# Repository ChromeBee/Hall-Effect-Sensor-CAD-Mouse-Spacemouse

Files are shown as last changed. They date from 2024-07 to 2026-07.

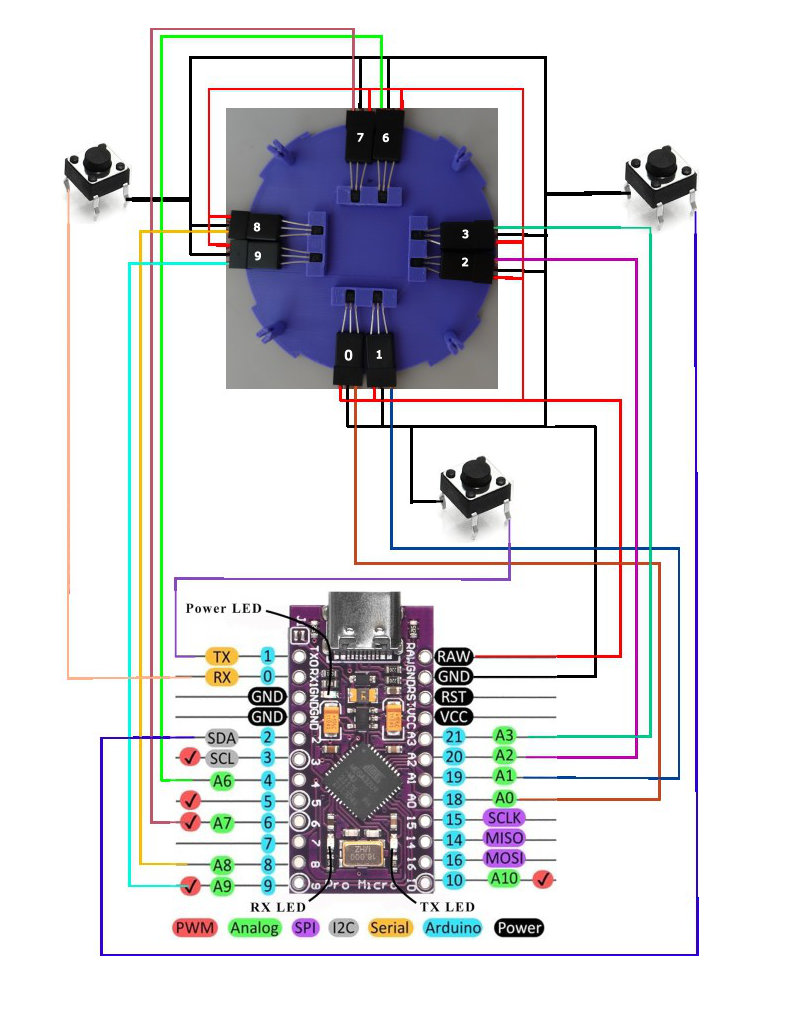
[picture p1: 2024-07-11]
HE Spacemouse Wiring Diagram.jpg

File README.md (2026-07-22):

Hall-Effect-Sensor-CAD-Mouse-Spacemouse
A 6 degrees of freedom mouse for CAD programs using cheap linear Hall Effect sensors for position measurement

2HE Spacemouse

This started as a thought project based on the Teaching Tech $20 CAD mouse code. This code works with the 3D ConneXions device driver so any program that works with the 3D connexions Spacemouse will work with his $20 CAD mouse and also this one. If it hadn't been for his project and the resulting code, I wouldn't have even considered this.

Luckily the thought project turned into a real one as I did my research.

The linear Hall Effect sensors used are the (SS) 49e variety. They are very cheap, I bought a pack of 40 for £10. 8 are required for this project. They are arranged in 4 groups of 2. 2 of the groups are parallel to the x-axis and 2 parallel to the y-axis.
These sensors have 3 pins. VCC, GND and output. With power connected, the output should give a value of half way between VCC and GND. i.e. if 5v is connected then with no magnet field detected the output should be 2.5v. If the north pole of a magnet approaches the sensor the output should decrease up to to a minimum voltage of 0.86v while if a south pole approaches then the voltage at the output should increase up to a maximum of 4.21v.
Using these sensors, the operation of the mouse can be described in a couple of pictures.

HSE default position

The red dots represent magnets suspended a short distance above each Hall Effect sensor pair. In their resting position (shown above) the sensors values are measured. Any change from these measured values represents a move of the joystick.

HSE forward position v2 HSE forward position

If the joystick is pushed forward slightly, the magnets move closer towards two of the Hall Effect sensors on opposite pairs (A & C in the picture), increasing the magnetic field that they detect and further away from the other two (B & D) which will detect less.
Because we can present only one pole of the magnet, we are restricted to only half of the possible output range. I chose to have the north pole being the one closest to the sensors as the analogue to digital converter was returning a value over half its possible range so I was getting the greatest range of values this way. Although I didn't know it at the time, the Arduino Pro Micro we are using to measure the outputs, also has the ability of switching to an internal ADC reference of 2.56 volts. Therefore if we present north poles to the sensors we should expect each sensor to output between 0.86 and 2.5 volts. So we don't lose much resolution.
So for the picture above, the sensors with the magnets moving towards them will output a decreasing voltage, while the two where the magnets are moving away from them will output an increasing voltage. If we take the values for the sensors at their resting positions and subtract the current values then The resulting value will go up as the magnet approaches and down when the magnet moves away. We will call this the sensor value from now on.

Now by adding the resulting values for sensors A & C and subtracting the values for B & D we get a result proportional to the amount of movement. If the value is positive in our example above we know it is a movement towards Sensors A & C and if it is negative then it is a movement away from them.

HSE twist position v2 HSE twist position

If we twist the joystick then diagonally opposite sensors will show a decreasing voltage as the magnet approaches while the other sensor in the pair will show an increasing voltage as the magnet moves away. 

By adding the values from sensors A & D and subtract the values from B & C we get a result that is proportional to the amount of twist. In our example a positive movement number will be a twist in the clockwise direction and negative will mean an anti-clockwise twist direction.

If we apply these values to the linear movement formula, we find that the the increased value for A is cancelled out by the increased value for D and B cancels out C. So we can tell the difference between a twist and a push. The same logic applies to the other movements.

magnet movement

When the joystick is tilted towards a pair of sensors then both their outputs show a decreasing voltage while the magnets on the opposite side will be moving away from the pair below it and so the sensors will output an increasing voltage.
Of course, the other pair parallel to the other axis will operate in the same way for tilts, twists and linear movements in the other axis.

When we push down on the joystick, the magnets get closer to all the sensors so the voltage output drops in them all and when we pull up on the joystick, the magnets move further away from all the sensors, so the outputs will increase.

DSC05601 v2

I tried various designs before I came up with the one that I'm going to take you through below. Including ones with multiple magnets per sensor pair but that is irrelevant if you just want to build what I came up with.

<h2>That is the operation now here is the implementation.</h2>

This build is also available on Printables. There may be more build details there but there will always be more technical details here on GitHub.
https://www.printables.com/model/940040-cad-mouse-spacemouse-using-hall-effect-sensors

<h3> Parts list</h3>
<ul>
  <li>Arduino Pro Micro</li>
  <li>8 of (SS) 49e linear hall effect sensors</li>
  <li>4 of 10x5x3mm Neodymium magnets
  <li>8 of servo sockets and leads</li>
  <li>3 of 6x6x5mm small tactile switches</li>
  <li>1mm diameter piano wire cut into 8 lengths of 8mm each and 4 lengths of 15mm</li>
  <li>8 of 0.2x12x4mm tension springs ( wire diameter 0.2mm, total length 12mm, length of spring portion 4mm and OD of 4mm </li>
  <li>1 of M4x40mm bolt fully threaded.</li>
  <li>3 of M4 Nut</li>
  <li>4 of M3x20 bolts to secure the bolt plate and hold the sensor plate the correct distance from the magnet plate.</li>
  <li>12 of M3 nuts for the above bolts.</li>
  <li>10 of M3x4mm heat press brass inserts</li>
  <li>2 of M3x8mm to hold on knob</li>
  <li>4 of M3x6mm bolts to hold on base</li>
  <li>4 of M3x6mm or M3x8mm bolts to hold on case</li>
  <li>Heat Shrink tubing or Insulation tape or liquid insulation to cover wire to wire solder joints</li>
</ul>



The mouse is made up of several layers or plates. The bottom plate holds the Arduino pro micro. This needs to be wired to the sensors and optional switches. The wiring diagram is in it's own folder in this project directory.
coloured render of HE Spacemouse with labels

I am using servo sockets to hold the Hall Effect sensors, however the default wiring colours for servo connectors doesn't match what is needed for the sensors. The middle pin on a servo is 5v and the connector will normally have a red wire to this, however it is ground on the sensor. With the angled side face up and the legs towards you, the left most pin is VCC, the middle pin ground and the right most pin the output. I swapped the VCC and GND wires on the servo sockets to avoid confusion.



To reduce the wires connected directly to the Arduino, I have joined the VCC pins of each pair together, also the GND pins and a GND wire for a switch. Then joined the 4 wires of VCC wires from the sensor pairs together to a single wire to go to the Arduino and the same with the GND wires. To make sure that the wires weren’t too long and to make things easier to wire. I attached the M4x40mm bolt to the bolt plate and the bolt plate to the sensor plate. I then mounted the sensors in their appropriate holders and held them all in place with an elastic band. This is what is shown in the picture above. The band was also useful for holding wires I didn't need at the time out of the way. 



These are then wired to the Arduino pro micro together with the sensor and switch output wires.
The Arduino is then mounted to the 3d printed Arduino plate and held in place with a short length of filament.



An M4x40mm bolt is then attached to the Bolt plate and this attached to the Arduino plate using M3x20mm bolts



4 of the 0.2x12x4mm tension springs are attached to the bolt plate. These fit in the slots on the centre column and are held in place with short (8mm) lengths of 1mm diameter piano wire.
A second set of nuts is added to the 20mm bolts holding on the bolt plate, then the sensor plate is placed on top and the sensors slotted into place.



Loading the software on to the Arduino pro micro and setting debug level to 1, we can ensure, by bringing a magnet close to each sensor, that the sensor works, is correctly connected and which pole of the magnet is being presented to it. Once we have identified the north pole of the magnet we can glue 4 10x5x3mm magnets into the magnet holder. The north pole is the one that causes the numbers to decrease when moved towards the sensors. The north pole should face downward, that is towards the side of the magnet plate with a slot in the area were the magnets go.

<b>Note:</b> Setting debug to 1 sets the reference voltage on the arduino pro micro to 5V. This debug value is only used for the initial build to ensure the Arduino is wired correctly and that the north pole of the magnet can be determined prior to mounting the magnets on the magnet plate. The 5V reference value means that the numbers will change no matter which pole of the magnet is presented to it. If the numbers go up then it is the south pole, if the numbers go down then it is the north pole. In other debug levels, the reference voltage is 2.5 volts and the output values won't change if the south pole of the nagnet moves closer. This would make the initial setup debugging more difficult. I have added this note After reading notes on change request #78 on AndunHH's Spacemouse code repository which is a code change for a version of this mouse. See : https://github.com/AndunHH/spacemouse/pull/78 Once the magnets are glued into place and the wiring verified this debug level is no longer needed.



Once the magnets are glued in we can add m3 x 4mm heat pressed brass inserts on the magnet holder and the case also the base if it is going to be used. I just used a soldering iron to push these into the corresponding holes.

location of brass inserts

The diagram above shows the location of the brass inserts.

Now we need to mount the magnet plate to the mouse. It goes over the M4 bolt and the springs attached to the bolt plate have to be mounted to the slots in the magnet plate using 4 x 15mm lengths of 1mm diameter piano wire.



4 more of the tension springs are attached to the magnet plate in the same slots. A second M4 nut is added to the M4 bolt and the wire holder is put on top. 4 more pieces of piano wire of 8mm in length and placed on the wire holder and the springs lifted and fitted on these.



An optional washer and M4 nut can be placed on top.

Set debug level to 2 in the code and upload it. Now test the movement of the magnet plate and verify that numbers go both up and down on all sensors.

The base is intended to be a weighted base and should be filled with something heavy and non metallic. I was thinking of cement, epoxy resin or modelling clay. 

Mount the base (if you are using it) using M3x6mm bolts and the knob using M3x8mm bolts.



Now make sure the knob is high enough so that when the case is put on the knob is clear of the case and there is sufficient movement in all directions. If not, adjust the top nuts on the M4 bolt.

Next put the buttons in the holes in the case and place the the case over the mechanism aligning the cut-out for the USB connector with the connector on the pro micro. Bolt the case in place using either M3x6mm or M3x8mm bolts.

The CAD Mouse/Spacemouse is now complete.

<h2>The Arduino now needs to be setup to emulate the Spacemouse.</h2>

This is the same process as the teaching Tech model and is covered on their Open Source Spacemouse model's Printables page at https://www.printables.com/model/864950-open-source-spacemouse-space-mushroom-remix

The process is also covered in the comments in the Arduino sketch. It involves setting up a custom Arduino board that the 3D connexion software recognises as a Spacemouse Pro Wireless.

The 3D connexions driver is fairly flexible on the range of values the mouse sends to it for it to work. To have the most flexible range, both in positive and negative directions, with debug set to 1, and analogRference(DEFAULT) I.e. 5 volts, the outputs should be reading around the value of 342. If the analogReference(INTERNAL) is set then, the mid range value should be around 684. You can adjust the distance of the sensor plate from the magnet plate to adjust this. Each corner can be adjusted independently.

<b>24-Nov-2024 Update</b>
I have found that with the magnets I'm using that a distance between the magnet plate and the sensors of just under 4mm works best. I have a small dowel stick that I've used as a pointer in some videos and its diameter is just under 4mm. If it just about fits, with a push, between the magnet plate and sensor plate then I'm about at the correct distance.

If the mouse works for tilting and twisting but not lateral movements of left/right and forward/backward, then the gap is too large and should be reduced. 

I have also added the TPU cap keeper that I added to Printables a few days ago. This, printed in TPU, fits on the knob cap and holds it to the knob, if loose. It wasn't needed for my first build but a subsequent print using a differet brand of filament, I found the cap was loose. This solves that problem.
<b>End-of-update</b>

This is what I've been able to discover that the button report can contain. The Spacemouse pro wireless supports 18 programmable buttons although the code indicates more. There are 4 bytes in the report and depending on what bit is set to 1 it causes the following to happen.
<TABLE BORDER="1">
<TR><B><TD>Bit Number</TD><TD>Byte 0</TD><TD>Byte 1</TD><TD>Byte 2</TD><TD>Byte 3</TD></B></TR>
<TR><B><TD>bit 0</TD></B><TD>Configuration Screen</TD><TD>Rotate 90 degrees</TD><TD>-----</TD><TD>Shift key</TD></TR>
<TR><B><TD>bit 1</TD></B><TD>Fit to screen</TD><TD>-----</TD><TD>-----</TD><TD>CTRL key</TD></TR>
<TR><B><TD>bit 2</TD></B><TD>Plan View</TD><TD>-----</TD><TD>-----</TD><TD>TAB key/Disable rotate</TD></TR>
<TR><B><TD>bit 3</TD></B><TD>-----</TD><TD>-----</TD><TD>-----</TD><TD>-----</TD></TR>
<TR><B><TD>bit 4</TD></B><TD>Right view</TD><TD>Hide design Browser</TD><TD>-----</TD><TD>-----</TD></TR>
<TR><B><TD>bit 5</TD></B><TD>Front view</TD><TD>Open File Explorer</TD><TD>-----</TD><TD>-----</TD></TR>
<TR><B><TD>bit 6</TD></B><TD>-----</TD><TD>Internet</TD><TD>ESC key</TD><TD>-----</TD></TR>
<TR><B><TD>bit 7</TD></B><TD>-----</TD><TD>Copy key</TD><TD>ALT key</TD><TD>-----</TD></TR>
</TABLE>

<b>09-Aug-2025 Update</b>
After a year of no code changes, I have made a couple.
The code has always had one pseudo button. By pressing the left and right buttons at the same time, it opens the 3DConnections configuration menu.
Now I have added two new pseudo buttons operated by pressing the front button and one of the other two buttons at the same time.

Pressing the front button together with the left button starts and stops rotation lock.
Pressing the front button together with the right button is fit to screen.

The three buttons pressed on their own change the view to plan, right and front.

All buttons can be reassigned to provide different actions through the 3DConnections configuration menu which you can get at by pressing both the button on the left and the button on the right simultaneously.

The actions described are for CAD software and may do different functions in different software. All have been tested with both Fusion and On-Shape.

The second change is to remove the Speed parameter in the code. This reduced the amount of movement permitted to 80% by default. As this function is also provided by through the 3DConnections configuration menu, it was redundant to have it in the code as well. This was a left over from the Teaching Tech Big Foot code which this code was originally based on.

You don't have to use my code with this mouse. I will point you to AndunHH's excellent GitHub spacemouse repository:
https://github.com/AndunHH/spacemouse

This code has frequent updates from multiple people, supports different mice hardware designs including this one and offers support for additional accessories such as LEDs and scroll wheels. The code is much more sophisticated than mine.

<b>14-Aug-2025 Update</b>
I have modified the code again. I never used the buttons on the mouse until recently. Having found the 'fit to screen' and to a much leser extent, 'rotation lock', useful. I decided to use the left and right buttons directly to implement these. That meant removing the 'Plan view' and 'Right view' from these buttons. I then decided that the front button should cycle through the three views. So now pressing the front button will give a different view on each press, cycling from 'Front view' to 'Right view' to 'Plan view'. The front button together with the left button now rotates the view by 90 degrees and the front button together with the right button removes the project browser in Fusion and brings up a number pad in On-Shape. This is effectively implementing the function of 8 buttons using only 3.

Pressing the left and right buttons together brings up the 3Dconnections configuration menu as normal.

If you are intending to re-map the buttons, then having a button that changes what button it is pretending to be each time it is pressed makes that more difficult, however by setting the variable cycleButton from true to false will stop this and change the mapping back to the previous version.

<b>20-May-2026 Update</b>
This is going to seem like a blog post.

There are three changes been added to the code, all around movement. I'm going to talk about them in reverse order.

The last change added (C012) uses all the sensors in all movement calculations. Previously only the z axis movements did this. I had tried this change previously but had to roll it back when it made the mouse behave worse but I subsequently realise that was because I made a mistake in the formulas I used, so now they are back and working. If you prefer the previous movement calculations you can have those by commenting out the line #define include_C012

The next change (C011) is, I have added weights to all the movement calculations. I thought zoom was too sensitive and wanted to reduce it while increasing the sensitivity to X and Y axis lateral movement. So now each movement direction has a weight associated with it that is used to calculate how much the movement contributes to the total movement seen on screen. After playing around with various values on both my mice for several days (one with the crossed 85A TPU springs (see https://www.printables.com/model/1087923-hall-effect-spacemouse-cad-mouse-with-tpu-springs) and one with Innerbushmans alternative magnet plate 95A TPU (See https://www.printables.com/model/1566497-alternative-tpu-suspension-for-spacemouse)), I have ended up with values that are almost back to what the original code had built-in when I was only averaging sensor pair values (i.e. if I used 4 sensor pairs in the calculation I divided by 4. if I used only 2 sensor pairs, I divided by 2). This change works by multiplying each movement with its associated weight and dividing it by a global weight divisor. You can make the mouse more sensitive and react faster in the required directions by increasing the weights or globaly by decreasing the weightDivisor value.  I had the transXWeight and transYWeight set to 12 and the transZWeight set to 2 for a while before deciding that, for me the mouse was too sensitive on X and Y axis movement and the zoom was too slow. I encourage you to play with values and see what works best for you.

This change also opens up the possibility of using, for example, one of the double button pushes that I never use to switch the mouse between different sensitivities by using the button push to change the weightDivisor value between a set of pre-set values. That would be pretty simple but then you'd want some way on knowing what the mouse was currently using. The obvious answer would be one or more addressable LEDs whose colour would indicate the pre-set in use. 

The final change (C010) and the first added to the code is actually by Jonas Edvinsson on Printables. He added and posted a snippet of code that ignores small accidental movements that are below a particular threshold of the main movement. By default if a movement is less than 35% of another movement then it is ignored. I added this shortly after Jonas posted it but had other changes I wanted to try to see if they impacted his code. This may affect mouse calibration so I have included a method of excluding it by commenting out the line #define include_C010.
I hope you like these changes.

In other news, one of my mice died. I thought it was Pro Micro but it turned out it was a short across the 5V to ground on the sensor plate. Naturally it was the mouse where the sensors are stuck in using liquid insulation and it was no longer liquid nor soft. I couldn't remove any of the sensors so I decided to construct a new sensor plate and wanted to try an new method of getting power to all the sensors.

Two wiring options

I finally decided to use copper tape and it works perfectly, even if the changes I made to the sensor plate for it are less than ideal. I still used liquid insulation on the sensors to protect the sensor wires. I hope I don't regret it.

new sensor plate wired

Later I found a 1.25mm picoblade connector on my desk and discovered the 49e hall effect sensor leads fit beautifully and it is so much smaller than the servo connectors. If I need to construct a new sensor plate again, I'll be using these to connect up the sensors.

Picoblade
<br>
<b>22-Jul-2026 Update</b>
I've been thinking about the deadzone for the last couple of weeks. I have quite a high value of 40 for this, while from the comments on Printables and other places, some people are using a much lower value, even as low as 4. 
There are 3 main reasons for having a deadzone.
<ul>
<br>
<li>The first reason is to ignore jitter or variations in the readings the Arduino's analog to digital converter gives when reading the sensors output voltages when in its resting (in the centre position). When viewing debug outputs, the numbers appear to jump about a lot but when I measured the maximum variation over 1000 readings I found it was only 2 across all sensors. This means that a deadzone value just above this would be sufficient for this reason. </li>
  <br>
<li>The second reason is to deal with any possible failures in the centring mechanism in returning the mouse to the exact same resting position after any movement. No matter if the centring mechanism uses metal or TPU springs, rubber, elastic, silicone or some other means, the centring may not be perfect and we want to ignore any minor variations in returning to this position.</li>
  <br>
<li>The third reason is personal preference. Is the mouse too twitchy or not sensitive enough to your touch?</li>
  <br>
</ul>
I'll stick to a value of 40. This works best for me.

<b>More code changes</b><br>
I've also made a couple of updates to the code.

<br>The first is related to the above. I've added a routine that will auto recentre the mouse if the readings for the current centre resting position is more than a certain threshold value away from what was previously recorded (C013). It determines this by ensuring all measurements, for a period of time, remain within this threshold of what it believes is the new centre position. I tried other methods for auto re-centring but this one seems to work best.
<br>
The other change is related to switching between different sensitivities. Something I mentioned considering in my last update. By pressing the centre and right buttons at the same time, it will switch between normal, half and quarter sensitivities (C014). This change was enabled by a previous change (C011) which allowed different movements to have different weighted priorities. 
Both these changes can be switched off by commenting out the associated #define line that says to include them.
<br>
I also did a bit of a tidy-up to the code.

Shield: [][cc-by-nc-sa]

This work is licensed under a
[Creative Commons Attribution-NonCommercial-ShareAlike 4.0 International License][cc-by-nc-sa].

[][cc-by-nc-sa]

[cc-by-nc-sa]: http://creativecommons.org/licenses/by-nc-sa/4.0/
[cc-by-nc-sa-image]: https://licensebuttons.net/l/by-nc-sa/4.0/88x31.png
[cc-by-nc-sa-shield]: https://img.shields.io/badge/License-CC%20BY--NC--SA%204.0-lightgrey.svg

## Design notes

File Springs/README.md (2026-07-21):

<h2>Springs</h2>
I have had a large bag of 0.2 mm tension or extension springs for years. The smallest length of spring in the bag, 12mm, is what I've used for this project.
The exact same spring as I've used seems to be difficult to find at a reasonable price. Even though I don't need them, I thought I would try a couple of different sizes to see how they perform.
I bought some 0.4x12x4mm and some 0.3x10x3mm springs from Amazon UK.

DSC05641 small

I mounted the springs on the bolt plate/magnet plate/wire holder as they would be in the completed CAD mouse but left off the sensor plate. 
In the photo the purple/pink one on the left has the 0.4x12x4mm springs, the grey one in the middle has the 0.3x10x3mm springs and the final blue one on the right is my prototype with the 0.2x12x4mm springs.
All work but the effort needed to move them varies. The 0.4x12x4mm springs, in my opinion, requires too much force to move.
The 0.3x10x3mm springs seem to require just slightly less force to the 0.4x12x4mm spring. The shorter length meaning that the spring is stretched more and offers more resistance
The 0.2x12x4mm springs are very light to move in comparison to the other two.

The springs are stretched to about 20mm in the home position so a longer spring should work and being under less tension, it should be easier to move.
However it needs to be short enough to pull the magnet plate back to the home position when the mouse knob is released. Remember that the tension can be adjusted somewhat by moving the wire holder further up or down the M4 bolt.

Another way to reduce the tension is to install a second wire holder on the bolt for the lower springs. The picture below shows an example of this. Although in the example it is just above their original position. The wire plate could be moved further up the M4 bolt.

DSC05642 crop small

Another example with the plate moved further up the M4 bolt.
DSC05650 small

I thought of another way of reducing the tension when using 0.3x10x3mm springs. Fewer springs.
DSC05654 small

I removed alternate springs from the upper and lower sections. This seems to work very well. It still centres and moves in all directions but easier.

A search of eBay.co.uk for 0.2mm tension springs does provide listings of some suppliers of 0.2x10x3mm and 0.2x15x3mm springs. I haven't tried them but both sizes should work (in theory).

-------------
YouTube recommended a video on the IndyMower to me. https://youtu.be/UnKOp4rhu7I?si=PoE8raFwQZSphymA
In this video Nicodem Bartnik used TPU springs as part of a bumper sensor. YouTube has been recommending a lot of TPU videos to me recently so I took the hint and tried to 3D print TPU springs for the mouse. When I was going through the original thought experiments prior to starting anything, I had considered using those small rubber bands that were popular about 10 years ago for making friendship bracelets and other such items.

The TPU spring I've come up with is printed flat and has a custom Wire holder (now TPU holder).

DSC05643 small
DSC05644 small
DSC05646 small

This "spring" has a square cross section of 2mm across. Although it works, the tension is too much to allow the mouse to move freely. So I reduced the size to 1mm cross section.
DSC05648 small

This works much better. Certain movements are of equivalent tension to the 0.3mm springs while other movements are easier. It certainly feels usable.

I'm going to stick with my 0.2mm springs but I've put the STL files for the 1mm crossection TPU spring and the matching holder in a subdirectory here should anybody wish to try it.

<b>18-Aug-2024 Update:</b> For some reason, I can't leave this alone. I modified the design of the TPU spring and created STL files for a 0.8mm and a 0.6mm version. I have put these in the spring STL directory. I was going to leave it at that but then I decided to print them. I've tried both in one of the test prints. The 0.6mm one feels quite like the 0.2mm springs I'm using and the 0.8mm one just adds a bit more tension. I don't know if these will last long term but they are cheap to make and worth a try if you have difficulty getting the springs.

<b>16-Nov-2024 Update:</b> I think I've cracked it and now have the perfect TPU "spring" version. It might even be better than the normal spring version.
Mechanisim and case

This uses two TPU "springs" that are slightly longer and with thinner mounting hooks so that two of these "springs" can be used at the same time. One of the issues with the TPU springs was that a pendulum like rotatary oscillation could occur. It was simple to eliminate by twisting the two TPU hooks located above and below the magnet plate in opposite directions. This twist in the springs would stop the oscillation but also put a rotational strain on the M4 nuts which could cause them to loosen over time. This design counteracts that but applies the same principle.

<b>Additional parts needed:</b>
<li>2 prints of either of the "Thin TPU spring 0.6x16mm.stl" or "Thin TPU spring 0.6x17mm.stl" obviously printed in TPU. (I used 85A TPU)</li>
<li>1 print of TPU Bolt Plate printed in PLA. This is just a shorter version of the orininal bolt plate without spring mounting slots. The original can still be used.</li>
<li>2 prints of the TPU hook.</li>
<li>1 print of the magnet plate 0.3 from the original model. This is the magnet plate for 0.3mm springs.</li>
<br>
I am currently using the "Thin TPU spring 0.6x17mm.stl" with the TPU bolt plate. I have used both "springs" with both bolt plates and all combinations work. It is just down to how tight you want the mouse to feel. 

The two "springs" are mounted so that one twists the mechanisim on one direction while the second twists it in the other cancelling out the rotational strain.
I hope seeing this in pictures helps to explain what I mean.

Parts for TPU assembly

One spring is mounted as normal to the TPU hook plate.

Added to lower bolt plate

The second one is also added to the same hook plate. I have mounted the first one with the end hooks on the bottom TPU Hook mount and the second with the centre on the mount. That is just how I did it and it doesnt really matter how it is done. I then mounted this to the bolt plate using an M4 40mm bolt and an M4 nut. <b>Note the spring is mounted so the ends are in the middle of the area that sits below the sensors.</b>

Magnet plate added

To add clarity, I have added the second TPU hook plate and magnet plate at this point but it should be mounted to the arduino plate and passed through the sensor plate before these are added. The magnet plate is connected as normal to one of the TPU springs.
Second set conneted to magnet plate

The second spring is now connected to the magnet plate but its mounts are connected to an ajacent slot to the previous spring. In my case I rotated the magnet plate slightly counter clockwise and located the spring in the next slot.

completed mechanisim

I then did the same again with the end of this spring when mounting it to the top TPU hook, rotating it counter clockwise so the end fits in the next slot along from the one that is vertically above the slot on the magnet plate I have just fitted the middle part of the spring.

completed mechanisim

The printed washer and final M4 nut go on top. The nuts should be tighted in such a way that each magnet is centered over a sensor pair.

Assembled device front and high

To complete the mouse, I have taken the idea from the build by Rares Paul on Printables and soldered the Vcc leads of each of the sensor pairs together and conected the Vcc of each pair together with a wire then repeated the same for the ground leads (rather than use the servo connectors used previously). While Rares Paul used hot melt glue to insulate the soldered leads, I used liquid insulation because I had some. The result, I think, looks quite neat. I have also added silicone none slip feet to the arduino plate as trialed in my video, https://youtu.be/bVAX9b2wB6A?si=tlR51EHB5Pdp-rGi - The final step is to put on the case and the knob.

Both mice together V1

When I printed the first mouse, I had intended to put it in a navy blue case which is why the internals were printed in the same colour. It first was in a grey case with a navy knob, before I put it in the dark grey and gold combo. This one I printed in the dark grey, intending to prnt the case in dark grey and a different bright colour but ended up with the Navy and Purple I used for my Cyberpuck design. 

I have decided they should swap cases. I now have the grey and gold mouse beside me with the TPU "spring" mechanism and I really really like it.

<b>24-Nov-2024 Update</b>
I was a bit concerned that the TPU spring holder being used could interfere with the mounts on the knob. I haven't experienced any problem, but once I had the thought, I coundn't let it go so I created a version with a smaller diameter TPU Spring Holder. This of course needed different TPU springs, so I created them as well. These can be found in the smaller TPU Hook subfolder of the STL folder. I picture of the resulting mouse is below.

small TPU hook mounted

<b>09-Aug-2025 Update</b>
Yesterday I came across an interesting YouTube short - A demonstration of a different design of TPU spring from someone called Trev-erse.

New TPU spring design by trev-erse small

If I were starting now, I might use this. I can see it attached to the base, PCB or sensor plate and directly to the magnet plate. it could make for a smaller design.

<b>14-Aug-2025 Update</b>
OK, I had to try it. I created a wave spring and a method to mount it to the mouse.
Full details in the 'experimental wave spring' directory.
https://github.com/ChromeBee/Hall-Effect-Sensor-CAD-Mouse-Spacemouse/tree/main/Springs/Wave_Spring_Experiment

<b>18-Feb-2026 Update</b>
InnerBushman on Printables has created a very interesting magnet plate TPU spring alternative that I want to bring to peoples attention.

CAD mouse small

You can find it at https://www.printables.com/model/1566497-alternative-tpu-suspension-for-spacemouse

I now have the 0.5mm version printed in eSun 95A TPU installed in my blue mouse and can confirm it work very very well.

<b>08-Mar-2026 Update</b>
InnerBushman, when he posted the alternative TPU spring for the Spacemouse, also included a case which was much smaller than the smaller case version I already posted here. That original smaller case version was for the TPU spring version I posted on Printables. InnerBushmans alternative spring doesn't require mounting points above and below the magnet plate so the mouse can be made much smaller.

When I designed the original case, I used variables (parameters in Fusion) to represent the various sizes, so using InnerBushmans case height as a guide, I changed some of the variables to have a case of the same height as his based on the original design. I have now posted that on Printables. Changes need to be made to bolt sizes to get the mechanisim to fit but the changes are simple.
See: https://www.printables.com/model/1626668-alternate-case-for-alternative-tpu-spring-for-spac

His design opens up other possibilities. I played around with using his spring higher up the knob where the fingers hold it. This should give the best control but while it worked well for most movements, it didn't work with tilt because of the changed pivot point. There was always a degree of lateral movement introduce with the tilt.

knob original magnet plate with Alt TPU spring

This however got me wondering... Can we put the magnet plate there and have the sensors mounted so they appear inside the knob itself? Then the only thing outside the knob would be the buttons and the pro micro ( and the mount for the sensors and the rest of the hardware).

I am aware that there are other mouse versions using similar springs such as this from LeoSpaceLab. https://youtu.be/LWE_vR1oFRo?si=dDvz3KJTkTcSgacW ( not a 6DOF mouse though the spring is) and Razberry on YouTube has a series where he tries to build the perfect mouse. This version by InnerBushman is for my mouse and and I know it works.

<b>21-Jul-2026 Update</b>
I woke up one morning wanting to create a dual material version of InnerBushmans combined TPU spring and Magnet plate. I let it lie for a couple of days but couldn't get it out of my head, so here it is.

3 PLA and TPU 3D printed springs

With this version the TPU spring is embeded within the PLA Magnet plate. You don't need a fancy printer to make this. The TPU spring is printed first, then the PLA outer part is printed but the print is paused two layers before the end (0.2mm layer height) and the TPU spring inserted before continuing the print.

In the picture above, The top version has the spring inserted the wrong way around. The middle one used 83A TPE and it was too floppy. The bottom one is the one I'm using at the moment and the spring part is printed in 95A TPU.

mouse with double material spring

Is it any better than the InnerBushman version? Good question. I think the answer to that is probably no. It feels slightly different but that could just be my imagination. Anyway the STL files for this are available the STL directory together with the FreeCAD design file.

Yes, this is the third CAD program I've used for updates to the mouse. I'm trying FreeCAD after a couple of issues with both Fusion and OnShape.

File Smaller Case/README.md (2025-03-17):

<h2>Smaller Case</h2>
<b>This is for the TPU spring version (see springs section or remix on Printibles.com)</b>

Smaller Case with Normal size

<p>This was not an exercise in reducing the size of the CAD mouse, but in making it easier to use.</p>
<p>I thought that moving the magnet plate closer to where the fingers hold the knob would perhaps make it easier to control without getting other unwanted movements</p>
<p>The theory is this. If you hold a broom handle horizontally in the middle, it is easy to move it vertically without it twisting. Now if you move your 
hand away from the middle of the broom handle, it will try to twist because the forces acting on it are unbalanced. The same is true with the CAD mouse. Without the case and knob, It is easier
to move and control the movement of the magnet plate by holding it directly. Adding the knob moves the placement of the fingers higher up
and the springs fight any lateral movement the fingers try to apply, applying a rotation force with the fingers as the pivot. Moving the magnet plate closer to where the fingers are placed 
should reduce this.</p>
<p>The idea was to move the magnet plate so its bottom was flush with the bottom of the knob. This doesn't affect the operation of the mechanism but maybe could make it
  easier to move the knob laterally.</p>
<p>The first step was enlarging the hole at the bottom of the knob so the magnet plate can fit and moving the mounts for the magnet plate further up the knob to a
position that aligns the bottom of the magnet plate to the bottom of the knob. This lowers the knob so the top of the case needs to be lowered 
by the same amount. Doing this breaks some of the rest of the model so other case changes need to be made to counteract this such as the
curve or the case needing made tighter and reducing the internal lip so that it doesn't interfere with the bolts.
</p>
<p>The internal mechanism remains unchanged. The only changes are to the knob and the case and the buttons (1mm longer).
I have also hollowed out the knob cap more so there is less chance it interfering with the M4 bolt, though I'm still using the original cap version.</p>
<h2> Is it worth it?</h2>
<p>Good question. I can't detect any major improvement with the movement so if you are happy with the original version, I wouldn't change it.
If you fancy a smaller version, this is only 6.25mm smaller but why not try it. It only costs the price of the filament and 4 brass heat press inserts.</p>
<h2>Update 17-March-2025 Base for smaller case</h2>
<p>I've added an STL file for a base to fit the smaller case version. Birdy67 on printables pointed out that the original design base didn't fit well with the smaller case. As I don't use the base myself, but use homemade silicone feet on the Arduino plate, I hadn't realised that the changes to the case would also affect the base.</p>
<p>Creating the base was easy as it was already part of the design and the modifications I made for the case were automatically reflected in the base so I just needed to export it. I have not printed it myself as I don't need it, so it is untested.</p>
<p>I apologise to everyone that has encountered this issue. I hope this new part fulfils you needs.</p>

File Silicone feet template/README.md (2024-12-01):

This directory contains the STL file for the template I used to create silicone non slip feet on the bottom of the Arduino plate on the CAD mouse as shown on the YouTube video https://youtu.be/bVAX9b2wB6A?si=D21PwzSWIdShig4m

I don't want to use the weighted base if I don't have to, so this is a way of holding the mouse in place without it. It would also be possible to use the same principles to add silicone feet to the Base as well but I haven't tried it.

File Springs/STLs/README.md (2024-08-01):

STL files for TPU replacement for the springs. The TPU Spring should be printed in TPU while the TPU holder needs to be printed in PLA or equivalent.
The standard Magnet plate can be used with this.
See README.md in Springs directory for more information.

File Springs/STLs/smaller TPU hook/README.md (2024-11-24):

This is the set of modified model parts for the small hook version of the TPU springs.

It is just the TPU springs with the smaller fixings and the associated hooks to hold them.
The smaller hook increases the distance between the magnet plate and the hook so the spring has to be slightly longer.

I am using the TPU Spring 0.6x18mm version. If you want a tighter feel, use the 17mm version.

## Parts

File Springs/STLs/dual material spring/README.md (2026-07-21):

The STL and FreeCAD design file for the dual material spring can be found here.

This is a remix of the Innerbushman alternate spring/magnet plate design. Print the spring in TPU first
then the magnet plate/ spring holder second pausing the print befor it closes the top. This is two layers before
the print finishes if printed with a 0.2mm layer height. You can then insert the TPU spring, checking that the 
orientation is correct and then continue the print.

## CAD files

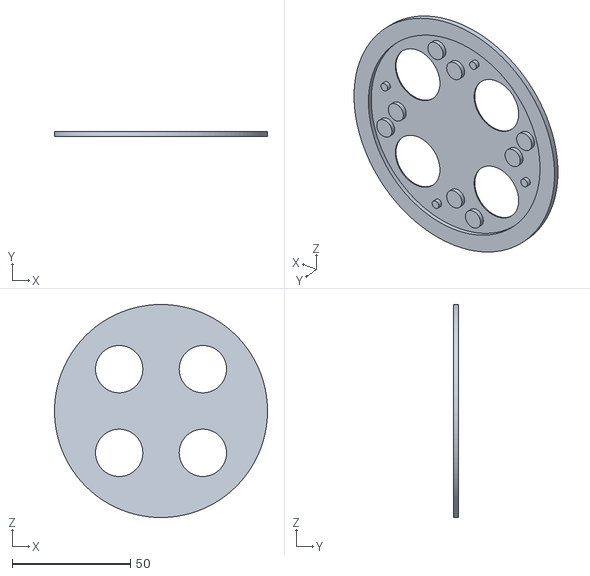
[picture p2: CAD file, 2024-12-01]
Silicone feet template/silicone template.stl
90.0 x 2.00 x 90.0

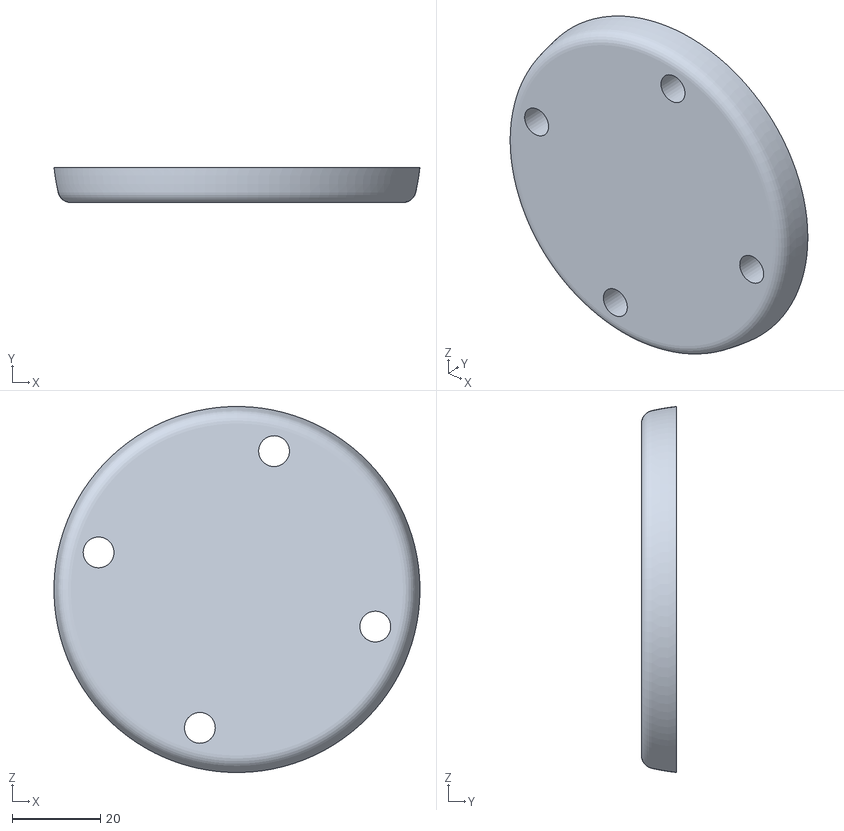
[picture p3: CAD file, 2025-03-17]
Smaller Case/Base for smaller case.stl
83.0 x 8.00 x 83.1

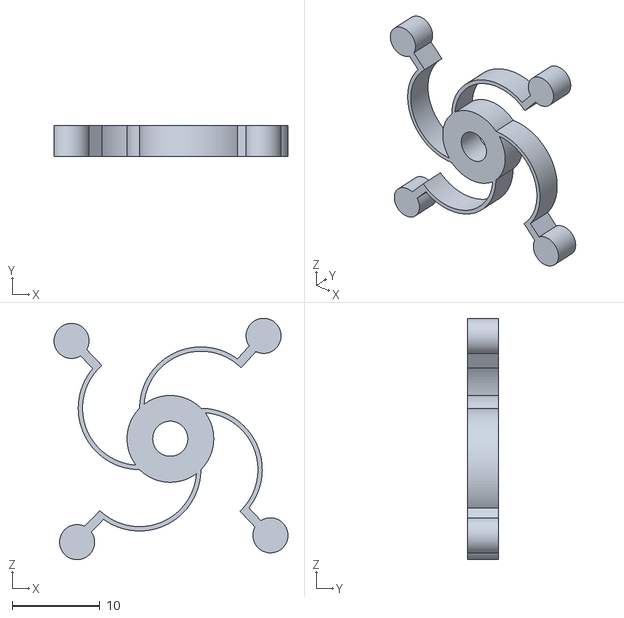
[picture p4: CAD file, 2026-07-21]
Springs/STLs/dual material spring/Alternate TPU spring for spring holder.stl
26.7 x 3.50 x 27.5

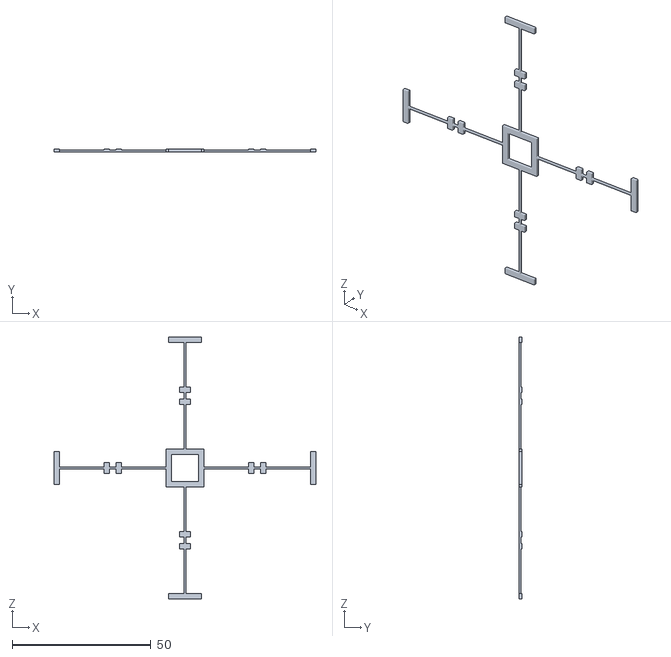
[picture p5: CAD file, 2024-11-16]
Springs/STLs/Thin TPU Spring 0.6x16mm.stl
94.4 x 1.00 x 94.4

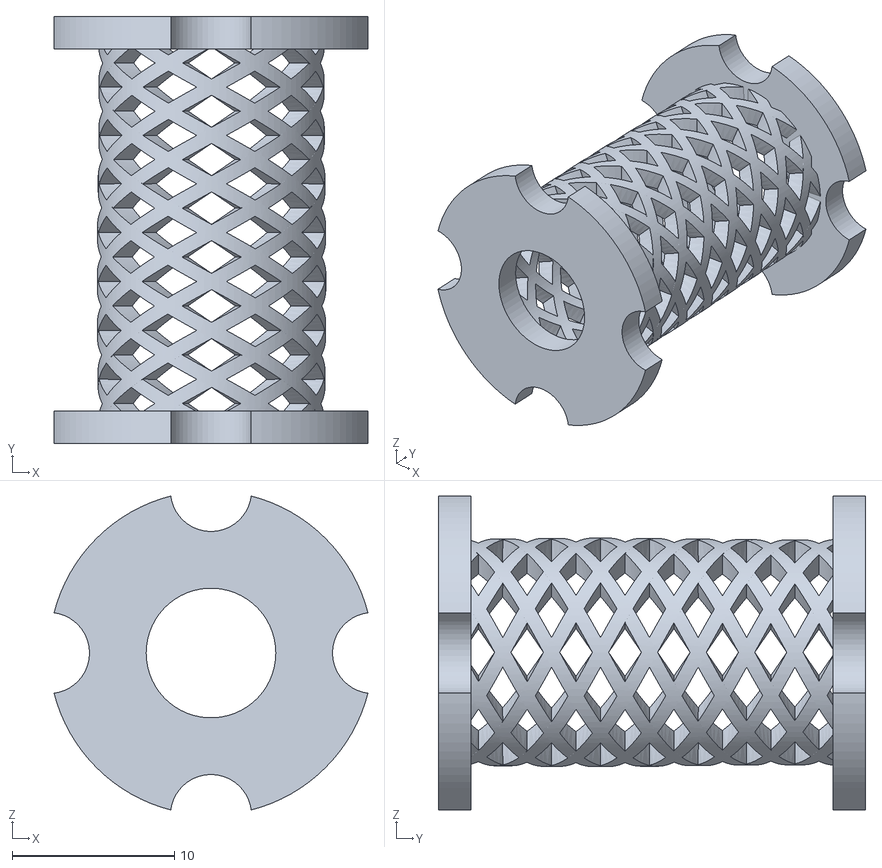
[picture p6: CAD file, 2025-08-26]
Springs/Wave_Spring_Experiment/Wave Spring for 95A TPU v3.stl
19.4 x 26.4 x 19.4

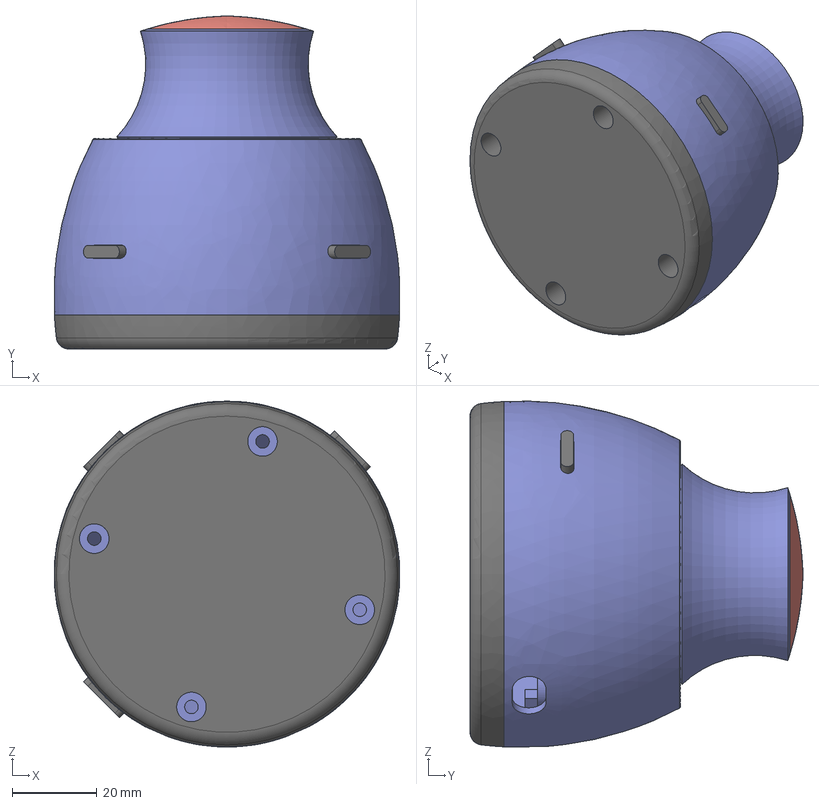
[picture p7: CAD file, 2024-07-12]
STEP file/Hall Effect Spacemouse.step
81.7 x 78.8 x 81.8 mm

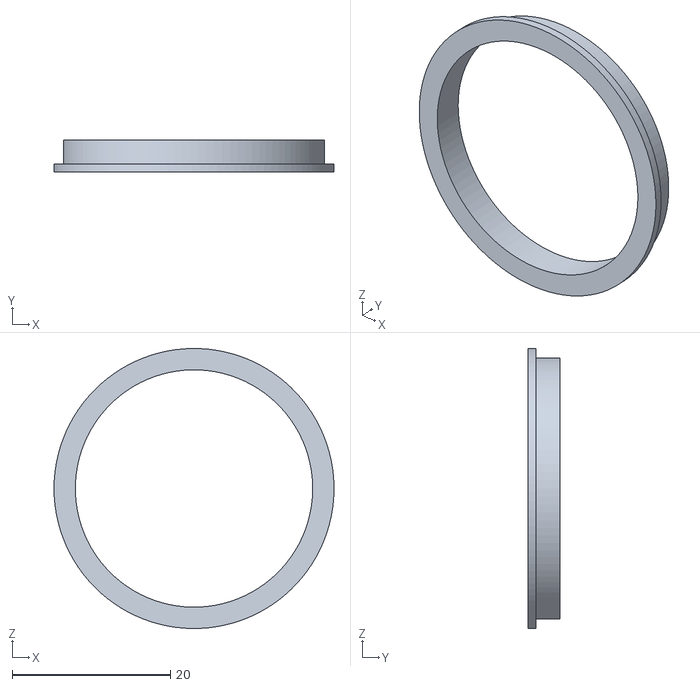
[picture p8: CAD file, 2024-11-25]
STL Files/TPU cap keeper.stl
35.4 x 4.00 x 35.4

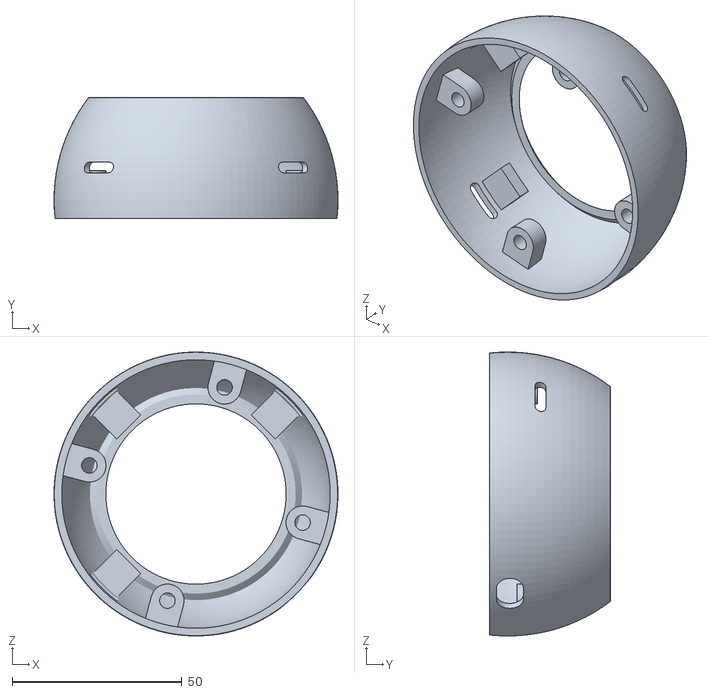
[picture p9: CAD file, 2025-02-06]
Smaller Case/Case (smaller).stl
83.6 x 35.6 x 83.6

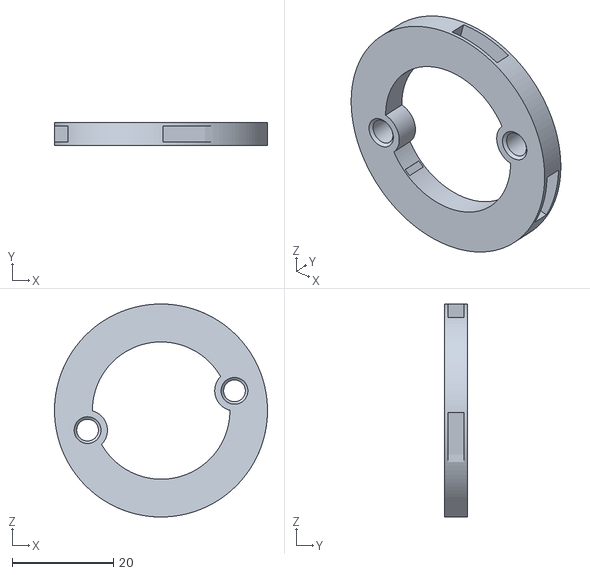
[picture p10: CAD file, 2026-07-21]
Springs/STLs/dual material spring/Alternate TPU spring holder with cutouts.stl
42.0 x 4.50 x 42.0

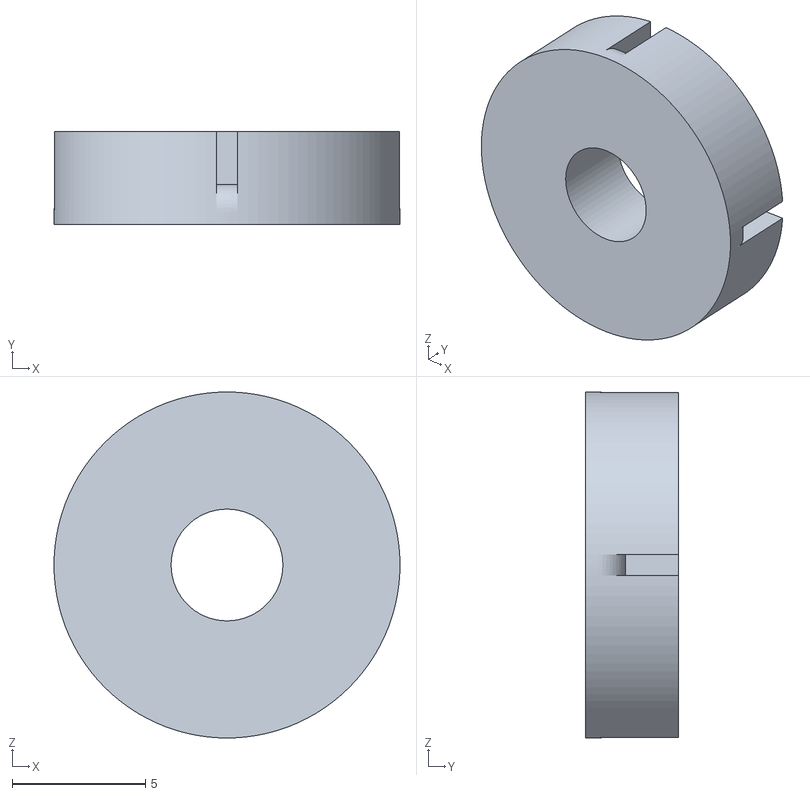
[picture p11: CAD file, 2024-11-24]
Springs/STLs/smaller TPU hook/TPU Hook V2.stl
13.0 x 3.50 x 13.0

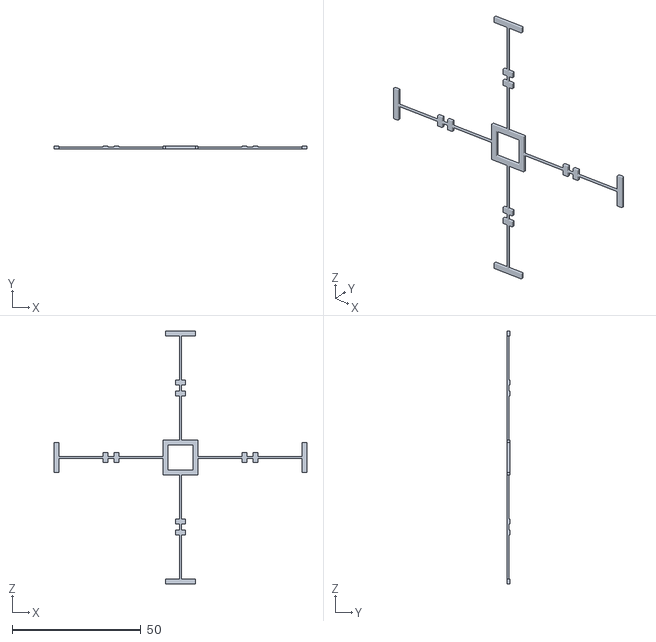
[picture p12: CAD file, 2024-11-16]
Springs/STLs/Thin TPU Spring 0.6x17mm.stl
98.4 x 1.00 x 98.4

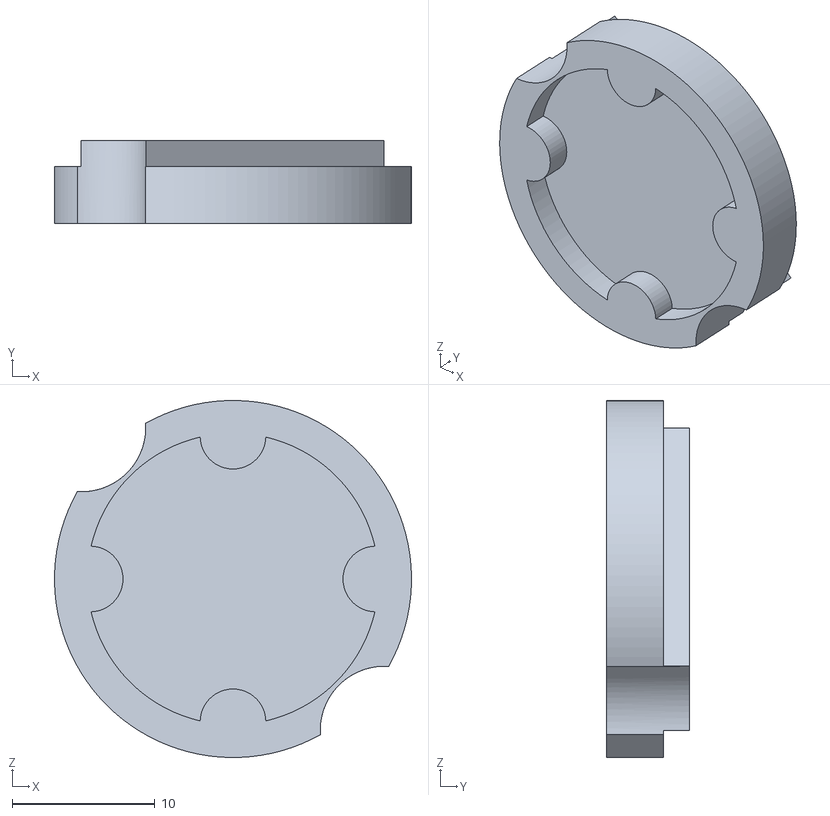
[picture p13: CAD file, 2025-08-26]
Springs/Wave_Spring_Experiment/magnet plate wave spring holder.stl
25.0 x 5.80 x 25.0

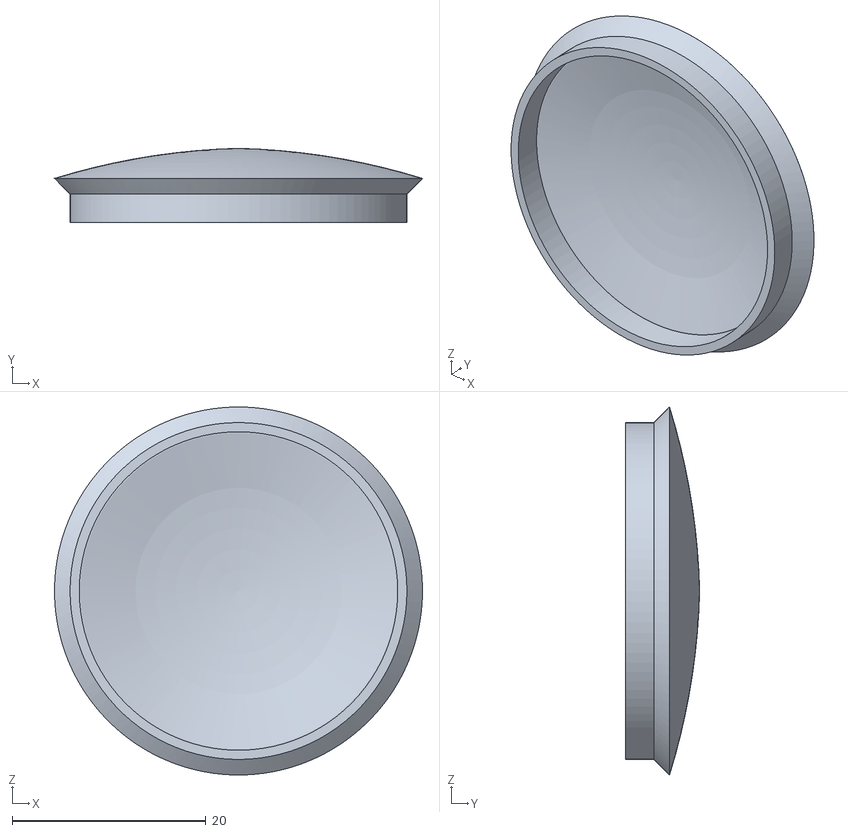
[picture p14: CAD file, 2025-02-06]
Smaller Case/Spacemouse knob cap hollow.stl
38.0 x 7.68 x 38.0

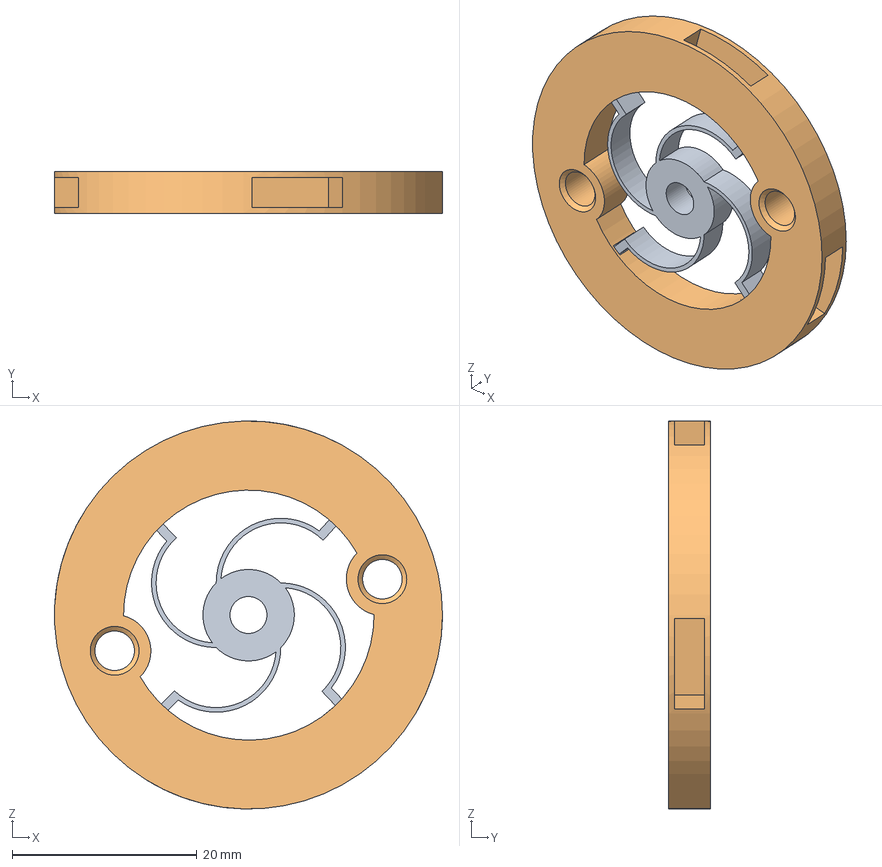
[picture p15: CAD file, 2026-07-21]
Springs/STLs/dual material spring/Alternate TPU spring.FCStd
42.0 x 4.50 x 42.0 mm
Alternate TPU spring for spring holder
Alternate TPU spring holder with cutouts

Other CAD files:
Springs/STLs/smaller TPU hook/TPU Spring 0.6x17mm V2.stl
Springs/Wave_Spring_Experiment/lower mount.stl
STL Files/Wire Hook.stl
Smaller Case/Spacemouse knob flush magnet plate.stl
Fusion 360 design file/Hall Effect Spacemouse.f3d
STL Files/Arduino Plate.stl
STL Files/Base.stl
STL Files/Bolt plate.stl
STL Files/Button.stl
STL Files/Case.stl
STL Files/Spacemouse knob cap.stl
STL Files/Spacemouse knob.stl
STL Files/Washer.stl
STL Files/magnet plate.stl
STL Files/sensor plate.stl
Smaller Case/Button v3 (extended -smaller case).stl
Springs/STLs/Bolt plate for TPU springs.stl
Springs/STLs/TPU Hook.stl
Springs/STLs/TPU Spring 0.1x15mm.stl
Springs/STLs/TPU Spring 0.6x15mm.stl
Springs/STLs/TPU Spring 0.8x15mm.stl
Springs/STLs/smaller TPU hook/TPU Spring 0.6x18mm v2.stl
Springs/STLs/smaller TPU hook/TPU Washer.stl
Springs/Wave_Spring_Experiment/Hall Effect Spacemouse smaller V3.step
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

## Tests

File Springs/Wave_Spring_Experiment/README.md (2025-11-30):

<h2> All the files associated with the attempt to use a 3D printed wave spring with the mouse are located here.</h2>

This started when I saw a youTube short from Trev-erse which showed a TPU 3D printed wave spring. https://www.youtube.com/shorts/o8dnB7d3OEM

OK. So I had to see how a 3D printed wave spring would work in the hall effect space mouse.
Wave spring printed parts

I designed a wave spring as described in the video (stacked sine waves) and mounts to hold it in the correct position in the mouse.

wave spring assembly
wave spring installed

Unfortunately, the wave spring in its current iteration needs stifening (printed with 85a TPU). With the knob on, it wobbles too much to be useful. I was concerned that this may be the case. Anyway, if you want to experiment with this then the STL and design files are in the wave spring subdirectory.
UPDATE: I've printed it again in 95A TPU and it works!!

<b>18-Aug-2025 Update</b> Ok, so I've modified the TPU wave spring design to have three wave springs and this works when printed in 85A TPU!!! It is too stiff when printed in 95A TPU.

Triple wave spring
Triple wave spring installed

It is a bit difficult to see in the photos so I have taked a screen shot from Fusion to show it clearer.

Tripple Wave Spring drawing

I didn't explain on the initial update that the knob was modified slightly to enlarge the mounting tabs so that they hold the top of the wave spring assembly in place. I modified the knob for the smaller case version so that meant I had to print the rest of the case as the mouse mechanism I originally used for these experiments was originally in the original sized case. So this is what it now looks like.

Triple wave spring cased v2

The feel of the wave spring mouse is different to the normal TPU 'spring' version but closer to the original normal spring version. It is easier to move lateraly without accidentaly rotating at the same time. Is it too easy to move? That would be up to the individual. It seemed too sensitive in 123D Design but I had never used a spacemouse with that program before but it is fine with Fusion and On-shape. I did turn down the sensitivity through the 3DConnexion menu.

I sized the wave spring straight from the CAD design, so the knob is at the correct height for the case. It would be relatively easy to create other sizes, if needed, and all the separate components are available in the design file to make your own.

This seems to be stretching Fusion and there are notable pauses if you change any of the variables used in the design to resize individual parts of the spring. Feel free to experiment.

<b>26-Aug-2025 Update</b> OK a bit of a redesign. Looking at the original still from the Treverse video, I thought I could create the spring using overlapping spirals and this would likely put less strain on Fusion when processing it (a lot less strain). So I present version 2.

spiral spring parts

The original version was a bit ackward to mount so I designed this so that the magnet plate didn't have to be mounted on the spring before the spring was mounted in the mouse body.

spiral spring mounted

Now the top of the spring can be folded and pushed through the magnet plate.

Spiral spring mouse assembled

A cap is placed on top of the spring and this holds the spring in place when the knob is screwed on.

spiral spring with cap mounted
spiral spring mouse from above

The design is parametric so if you change any of the Wave spring variables in the fusion design you can change the stiffness, length, width or other features of the spring.

I have two versions of the spring. A single spring for printing in 95A TPU and a triple spring version for 85A TPU. Print them standing vertically without support. All files are in this directory.

<b>30-Nov-2025 Update</b>
Now a version of the wave spring is available in OnShape. Look for "TPU Spiral Wave Spring for CAD mouse".

OnShape

The mountings for this are slightly different from the ones in the Fusion file so take them for OnShape as well.

The Variable Spring_Horiz_Width set to 1mm seems to work quite well with 95A TPU while a value of 2mm works better for 85A TPU, but feel free to play arround with the various variables. Making the holes different shapes and sizes will affect how the mouse feels. Reduce the number of spirals to make it lighter to use and increase them if it is too light for you. Increase the Spring_Horiz_Width to make it harder to move horizontally and increase the Spring_Vert_height to make it harder to pull and push.

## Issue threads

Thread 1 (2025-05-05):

Would a custom PCB being designed for you be of any use?

alextrical, 2025-05-05:
Hi

As my day job im an alectrical engineer for a open source smart speaker project (Future Proof Homes)

Just stumbled upon your project, and thought that it could benefit from a Custom PCB being designed, I wondered if you would be interested in some help to get that setup for this project.

I would hope that it could lower the barrier of entry to users who arent as happy to solder components manually.

Kind regards
Alextrical

alextrical, 2025-05-06:
No worries, I was invisioning a more all in one PCB, comprising of fully SMD parts, and fitted in the place of the "Sensor plate"
I will give Michael Roth a poke and see if he in interested.

I generally dont like to Fork, but to push improvements to the main repo, otherwise things tend to get fragmented

ChromeBee, 2025-05-06:
Hi Alextrical,
For your information: DoTheDIY on YouTube commented on the 'Spacemouse in use' video that he had ordered smd hall effect sensors and was going to make a PCB version. That was 9 months ago. I don't know if he took it any further.

alextrical, 2025-05-06:
Unfortunatly it does look like he took it further and made a closed source design, locked down & closed source firmware, and needs parts CNC plasma cut. https://cults3d.com/en/3d-model/gadget/ddsf
It seems to work with Windows only, but it is wireless bluetooth which is rather neat.

I was hoping to give something back to the community through helping progress a awesome project like this.

ChromeBee, 2025-05-07:
His Nebula mouse is different. He uses 3 TL1493D 3 axis hall effect flux sensors to detect the movement. It is a much more complicated build than mine. I've looked on his discord and he has pointed some of this followers to this version if they are finding his too complex.

alextrical, 2025-05-07:
ooh, those sensors look amazing. I never considered that they would make an I2C hall effect sensor. though it does feel overkill using 3!

From an electrical point of view that really simplifies the control electronics required, expecially if used as designed/intended and only needing One sensor IC ;)
https://www.nexty-ele.com/nat/wp-content/uploads/sites/3/2018/11/Infineons_generation-3D-Hall-Sensor-TLI493D-W2BW_20210301-2.pdf

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
though it may be that a single magnet & sensor can only determine 3 DoF?

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

We could easily use a RP2040, and also read in the sensors you use via a I2C ADC, that would also work nicely, or even use a multiplexer to the onboard ADC (though the ADC is only 8 Bit, but it could be enough, but it depends on how fast it needs to be read for a responsive user experience)

ChromeBee, 2025-05-07:
I think you need at least three of the sensors to get the 6DOF detection. His BOM gives three different part numbers for the sensors which, I've just realised, is probably because they need to have different I2C addresses.

You can read I2C on the pro micro, you don't have to go to an RP2040 unless it gives you other advantages.

And yes, you can use an I2C ADC with the hall effect sensors I use but are you then over complicating what I think is currently a simple design?

alextrical, 2025-05-07:
I'm starting to believe that 6DoF needs more than a single sensor too.

Correct the different part numbers are for the different baked in I2C addresses

The advantage of the Rp2040 is its a highly available and cheap chip to build with.
The bare Rp2040 is $0.97 (at 10pcs qty) vs the ATMEGA32U4-MU $4.79 (at 10pcs qty)
The disadvantage of the RP2040 is that it only has 2 ADC inputs, but can be augmented with some external ADC.

I agree that making a PCB can complicate the electrical design, but can greatly reduce the complexity of assembling the device by the end user. I will take a look at drafting up a PCB sometime this week using the same Hall sensors you are, the RP2040 and an external multi port ADC. Idealy i would like to get the cost of manufacturing down as low as possible for small batches at JLCPCB (i.e. getting a PCB made for under $15) time will tell how much it actually is, and if its cheap enough to be worth continuing the idea

ChromeBee, 2025-05-07:
Good luck!
Before you start, I will point you at: https://github.com/AndunHH/spacemouse
AndunHH has written quite sophisticated software for the joystick version of the Spacemouse and Change Request #78 by JarnoBoks modifies it for this Hall Effect Sensor version. All runs on the Pro Micro. I'm not sure if you go for the RP2040 with external ADCs what software changes would be required. Can it be integrated easily with AndunHH's code? Something to consider.
I'm not using his code at the moment but I have verified that it works and it is being maintained.

alextrical, 2025-05-07:
Thank you, I will try to get in touch with a few of those developers, and see where it takes me.

Closed 2025-05-06.

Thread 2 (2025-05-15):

All working but up/down

tdguchi, 2025-05-15:
Hi! thank you for sharing this all, i have been testing other implementations, and this one is the best of them

I have build it, using 0.25x4x12 springs, and i have tested it.

I have installed all, arduino and driver, and tested it on the "trainer"

firsts steps worked fine, up, down, back, forward, rotations... but the last one (when all is enabled)... its a mess, going up/down also rotates, rotation sometimes adds forward/backward....

When I check "dominant" in 3dconexion app its working (rotations are swapped and some more things) but i can go up/down back/forward and rotate, it works perfect.

What I need to tune?

I have used debug 1 (values from 160-600)
Also debug 2 gave me "good" results

My magnets are in a good distance, as I can move an rotate in every axis.... or the mixed result is a symptom that there is something wrong?

(My ss49e are from aliexpress maybe the are faulty and give noise)

Thanks in advance, if anyone needs more info to try to help me, just, ask.

And thank you again for this work!

ChromeBee, 2025-05-15:
I don't know for sure what the problem is. My suggestion is to check the wiring of the sensors.. If two of them are swapped then that could cause a strange effect. You say that the up/down doesn't work but don't say it it is moving the model up and down the screen which could be affected by a mis-wired sensor. (Moving the knob forward and back). Or moving the knob of the mouse up and down which is by default the Zoom function which shouldn't be affected by a mis-wired sensor.

The other possibility would be that one of the magnets is upside down but you should be able to detect that through the debug information.

tdguchi, 2025-05-15:
Hi! thanks for your fast reply.

All magnets are oriented (north to the hall sensors)

And yeah, i can move and rotate in every axis, but i need to move just a "bit" like a portion of a milimiter xD, then it works, if i use more displacement or rotation, then the mix shows.

Also the magnet thing is not perfectly paralel to the sensor, its just impossible for me to equilibrate all springs.

All sensors are well wired (i have tested everyone in debug with a single magnet)

As said, if I use "dominant" checkbox on 3dconexion app, all movements and rotations are better separated, that (i think) is a good point, so, magnets and hall are correct....

Also tried to increase the deadzone, but, i havent achieved any improve.

ChromeBee, 2025-05-15:
Deadzone only matters if the object on the screen moves when the knob on the mouse isn't.

I don't think the springs are causing a problem as ste setup for debug values other than 1 calibrates the mouse on startup, when you are not touching it and everything afterwards is relative to this.

Only thing I can suggest is to try moving the magnet plate closer  to the sensors and try that. It will give a smaller range of numbers but maybe your strange behaviour is because a magnet is to far from the sensor to register correctly during the movement.

With debug set to 2, you should see the number change as you move the mouse and the object in your cad program should move as well. When you do the movement that causes the problem, maybe a sensor that should be changing value isn't or has reached it's maximum or minimum possible value.

ChromeBee, 2025-05-15:
From the readme on the main page.

The 3D connexions driver is fairly flexible on the range of values the mouse sends to it for it to work. To have the most flexible range, both in positiva and negative directions, with debug set to 1, and analogRference(DEFAULT) I.e. 5 volts, the outputs should be reading around the value of 342. If the analogReference(INTERNAL) is set then, the mid range value should be around 684. You can adjust the distance of the sensor plate from the magnet plate to adjust this. Each corner can be adjusted independently.

Check if your getting around this.

Closed 2025-06-23.

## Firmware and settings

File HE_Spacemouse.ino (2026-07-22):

// This code is the combination of multiple works by others:
// 1. Original code for the Space Mushroom by Shiura on Thingiverse: https://www.thingiverse.com/thing:5739462
//    The next two from the comments on the instructables page: https://www.instructables.com/Space-Mushroom-Full-6-DOFs-Controller-for-CAD-Appl/
//    and the comments of Thingiverse: https://www.thingiverse.com/thing:5739462/comments
// 2. Code to emulate a 3DConnexion Space Mouse by jfedor: https://pastebin.com/gQxUrScV
// 3. This code was then remixed by BennyBWalker to include the above two sketches: https://pastebin.com/erhTgRBH
// 4. Four joystick remix code by fdmakara: https://www.thingiverse.com/thing:5817728
// The work by Teaching Tech involves mixing all of these. The basis is fdmakara's four joystick movement logic, with jfedor/BennyBWalker's HID SpaceMouse emulation.
// The four joystick logic sketch was setup for the joystick library instead of HID, so elements of this were omitted where not needed.
// The outputs were jumbled no matter how He plugged them in, so I spent a lot of time adding debugging code to track exactly what was happening.
// On top of this, He has added more control of speed/direction and comments/links to informative resources to try and explain what is happening in each phase.

// Spacemouse emulation
// Teaching Tech followed the instructions here from nebhead: https://gist.github.com/nebhead/c92da8f1a8b476f7c36c032a0ac2592a
// with two key differences:
// 1. He changed the word 'DaemonBite' to 'Spacemouse' in all references. 2. He changed the VID and PID values as per jfedor's instructions: vid=0x256f, pid=0xc631 (SpaceMouse Pro Wireless (cabled))
// When compiling and uploading, He select Arduino AVR boards (in Sketchbook) > Spacemouse and then the serial port.
// You will also need to download and install the 3DConnexion software: https://3dconnexion.com/us/drivers-application/3dxware-10/
// If all goes well, the 3DConnexion software will show a SpaceMouse Pro wireless when the Arduino is connected.
// *JC - John Crombie - I'd like to add a big thank you to Teaching Tech for this code. If it wasn't for this I wouldn't
// have been tempted to try to implement a Hall Effect sensor version. All my changes will be marked with a *JC comment
// All debug Serial.print statements have had the joystick output text has been renamed as HESx e.g. AX is now HSE0
/**********************************************
 * change log
 * C001 - 18-Jul-24 - Reversed default direction of Z rotation
 * C002 - 22-Jul-24 - Added state machine code to handle pressing two buttons at once to cause a third action and supress
 *                    suppress the default action of the two buttons pressed. Before I didn't supress the actions
 * C003 - 25-Jul-24 - Added define for movement3DC to switch between default 3DConnexion axis movement and Teaching Techs default movement
 * C004 - 04-Aug-24 - bug fix - Changed key reporting so that a zero report is sent when the final key is released.
 *                    Changed the place where duplicate keys reports are supressed. Used to be in the key routine now in the report routine
 * C006 - 08-Aug-24 - bug fix - After logical button was pressed, all buttons were being sent in state 4. Now corrected. 
 * C007 - 07-Aug-25 - Adding two more pseudo buttons. Achieved by pressing front button at the same time as one of the side buttons.
 *                    These give TAB/Rotate lock (Left and fromt button) and Fit to screen (Right and front button) by default
 * C008 - 09-Aug-25 - Remove Speed adjustment left over from TT code - This can be controlled through 3DConections configuration menu.
 * C009 - 12-Aug-25 - Changed centre button to cycle through three views if enabled with include_cycleViews being defined
 * C010 - 28-Feb-26 - Added code section by Jonas Edvinsson and added define to include it #define include_C010 comment this out to exclude it
 * C011 - 11-May-26 - Altered the weights of the various movements.
 * C012 - 17-May-26 - All sensor values change with any movement. For a lateral movement, say moveing the knob left, the main sensors are 0 and 7
 *                    where the magnet moves over them and 1 and 6 where the magnet moves off them, but the magnets also move off sensors 2, 3, 8 and 9,
 *                    giving a change in reading that contributes to the lateral reading. This change includes these sensor contributions to the movements.
 * C013 - 11-Jul-26 - Auto update center position, if drift detected. If the mouse sensor readings remain constant (within a set permitted variation) but
 *                    different from the current recorded center position by more than the same margin for a set amount of time then update the
 *                    recorded center position.
 * C014 - 16-Jul-26 - Added sensitivity selector. Press the right and front mouse buttons simultaniously to step between full, half and quarter sensitivities
 *                    This operates by stepping through 3 different weightDivisor values. This change was made possible by changes for C011
 * 
 ************************************************/
 
// Include inbuilt Arduino HID library by NicoHood: https://github.com/NicoHood/HID 
#include "HID.h"

// Define to include C010 code by Jonas Edvinsson. Calibrate the mouse first before including it.
// This change ignores small movement changes when there is a large one.
// Comment out the define to exclude it.
#define include_IgnoreSmallChanges

// Define to include C012 - just in case it causes problems
// This change uses all 8 hall effect sensors to calculate all movements.
// comment out the define below to exclude the change
#define include_UseAllSensorsForAllMovement

// Debugging
// 0: Debugging off. Set to this once everything is working.
// 1: *JC Output raw Hall Effect Sensor values. 176 - 862 raw ADC 10-bit values. 5V ADC reference
// 2: *JC Output centered Hall Effect Sensor values. Values should be approx -424 to +424, jitter around 0 at idle. ADC reference 2.56v
// 3: *JC Output centered Hall Effect Sensor values. Filtered for deadzone. Approx -424+DEADZONE to +424-DEADZONE, locked to zero at idle. Also button values. ADC reference 2.56v
// 4: Output translation and rotation values. Approx -500 to +500 depending on the parameter. *JC ADC reference 2.56v
// 5: Output debug 3 and 4 side by side for direct cause and effect reference. *JC ADC reference 2.56v
// 6: *JC Output debug info for pseudo key state machine. ( two keys pressed at once to simulate another key press)
// 7: *JC output debug messages for Auto recenter code
// 8: *JC output debug messages for sensitivity adjustment
int debug = 0;

// Choose between 3DConnexion default movement or Teaching Tech's
// With 3DConnexion you push the joystick away from you to zoom out and towards you to zoom in.
// lifting up the joystick moves up and pushing down moves down.
// With the Teaching Tech default, these two axis are swapped so that pulling up or pushing down the knob controls zoom
// and pushing away or pulling it towards you controls up and down. I prefer this.
// set to true for 3DConnection movement.
bool movement3DC  = false;

// C013 - detect drift of default home position and reset it 
#define include_AutoRecenter  // comment this line out to remove auto recentering code

#ifdef include_AutoRecenter
// if we get sensor readings that are above the variation threshold of the center point (for 1 sensor or more) and we get continous
// sensor readings within the variation threshold of this value for a set time then we assume this is our new center point
// and reset the stored centerPoints to these new values.
const int variationThreshold = 7; // Amount of drift permitted from the current centerPoints and the variations allowed in the new values
const unsigned long stableTime = 1000; // time readings have to be within the variation threshold in milliseconds to cause the new readings to be accepted as teh new centerPoints
// internal global variables for C013
bool greaterThanThreshold = false; // does the current values exceed the variation threshold
unsigned long startTime; // if so start a timer
bool withinBounds,firstTime=true; // Are the new values within the variation threshold. first time outside the threshold start timer
int oldCentered[8]; // what were the centered sensor value the last time through the loop
#endif
// end C013 setup

// switch between two modes of operation. The original mapping of buttons including pushing two at once or an alternative mapping where
// the front button pretends to be three different buttons mapping to three views.
#define include_cycleViews
uint8_t cycleInitialButton = 0; // Added to lowest pseudo button value
const uint8_t buttonDelay = 20; // 20ms wait time for second button to be pressed

// Direction
// Modify the direction of translation/rotation depending on preference. This can also be done per application in the 3DConnexion software.
// Switch between true/false as desired.
bool invX = false; // pan left/right
bool invY = false; // Zoom in/out or pan up/down // C003 *JC - 3DC default movement or TT default
bool invZ = true; // pan up/down or zoom in/out // C003 *JC - 3DC default movement or TT default
bool invRX = false; // Rotate around X axis (tilt front/back)
bool invRY = false; // Rotate around Y axis (tilt left/right)
bool invRZ = false; // Rotate around Z axis (twist left/right)

// C011 - different weights to different movements
// This change is to give more prominence to certain movements.
// For example it is more diffcult to move laterally than to zoom
// so to try and even things out we can give lateral movements a bigger
// weight than the zoom movement.
// This works by multiplying the actual movement by the weight applied 
// and dividing by the weightDivisor.
// NOTE : Integer arritmetic is being used so divide rounds down
const int  transXWeight = 7; // change to 6 for previous operational feel
const int  transYWeight = 7; // change to 6 for previous operational feel
const int  transZWeight = 3;  // change to 3 for previous operational feel
const int  rotXWeight = 6; // change to 6 for previous operational feel
const int  rotYWeight = 6; // change to 6 for previous operational feel
const int  rotZWeight = 4; // change to 3 for previous operational feel
int  weightDivisor = 12; // C014 removed the const

// C014 - Variable weightDivisor - Sensitivity adjusment
#define include_SensitivityAdjustment   // comment out to exclude C014 change and use press of right and front button together as normel button
const int maxNumWeightDivisors = 3; // number of values in array below
const int weightDivisorSelection[] = {12,24,48};
int currentDivisorIndex = 0;



// Speed
// Modify to change sensitibity/speed. Default and maximum 100. Works like a percentage ie. 50 is half as fast as default. This can also be done per application in the 3DConnexion software.
// int16_t speed = 80; C008 - remove this as it can be controlled through 3dConnection software


// Default Assembly when looking from above: *JC modified for Hall Effect Sensors (HES)
//      7 6          Y+
//       |           .
// 8 9 --+--2 3 X-...Z+...X+
//       |           .
//      0 1          Y-
//
// Wiring. Matches the first eight analogue pins of the Arduino Pro Micro (atmega32u4)
int PINLIST[8] = { // The positions of the reads *JC comments indicate which Hall Effect sensor is connected
  A0, // HES 6 o'clock left
  A1, // HES 6 o'clock right
  A2, // HES 3 o'clock near
  A3, // HES 3 o'clock far
  A6, // HES 12 o'clock right
  A7, // HES 12 o'clock left
  A8, // HES 9 o'clock far
  A9  // HES 9 o'clock near
};

// *JC added button list for digital inputs
int BTNLIST[3] = { // Button pin list
  0,
  1,
  2
};

// Deadzone to filter out unintended movements. 
// Increase if the mouse has small movements when it should be idle or the mouse is too senstive to subtle movements.
// Note that the 3d Connections also has its own deadzone processes
int DEADZONE = 40;
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
void loop() {
  int rawReads[8], centered[8];
  uint8_t buttonReads[9]; // C007 - *JC added two more values for two extra pseudo buttons C009 added another 3 pseudo switches to cycle views when button 2 (front) pressed

  // sensor values are read. range should be 176 - 1024 for debug levels other than 1 and 88-860 for debug 1
  readAllFromSensors(rawReads);
  // button values true or false
  readAllFromButtons(buttonReads);

  // Report back 0-1023 raw ADC 10-bit values if enabled
  if(debug == 1){ 
    Serial.print("HES0:"); Serial.print(rawReads[0]); Serial.print(",");
    Serial.print("HES1:"); Serial.print(rawReads[1]); Serial.print(",");
    Serial.print("HES2:"); Serial.print(rawReads[2]); Serial.print(",");
    Serial.print("HES3:"); Serial.print(rawReads[3]); Serial.print(",");
    Serial.print("HES6:"); Serial.print(rawReads[4]); Serial.print(",");
    Serial.print("HES7:"); Serial.print(rawReads[5]); Serial.print(",");
    Serial.print("HES8:"); Serial.print(rawReads[6]); Serial.print(",");
    Serial.print("HES9:"); Serial.println(rawReads[7]);
  }

  // Subtract centre position from measured position to determine movement.
  // *JC - As we are going negative with the readings, we make them positive
  // by subtraction them from the recorded centerPoints rather than the other was around.
  // C0004 - changed back to the original TT version to match the code from AndunHH 
  for(int i=0; i<8; i++) centered[i] = centerPoints[i]-rawReads[i]; // 
  // Report centered Sensor values if enabled. Values should be approx -256 to +256, jitter around 0 at idle.
  if(debug == 2){
    Serial.print("HES0:"); Serial.print(centered[0]); Serial.print(",");
    Serial.print("HES1:"); Serial.print(centered[1]); Serial.print(",");
    Serial.print("HES2:"); Serial.print(centered[2]); Serial.print(",");
    Serial.print("HES3:"); Serial.print(centered[3]); Serial.print(",");
    Serial.print("HES6:"); Serial.print(centered[4]); Serial.print(",");
    Serial.print("HES7:"); Serial.print(centered[5]); Serial.print(",");
    Serial.print("HES8:"); Serial.print(centered[6]); Serial.print(",");
    Serial.print("HES9:"); Serial.println(centered[7]);
  }

  // C013 -- cneck if mouse in home position but not centered
  #ifdef include_AutoRecenter
  if( greaterThanThreshold) { // always false the first time through. this indicates a possible change in the center position or user movement
    withinBounds=true;
    for(int i=0;i<8;i++) { // check if any sensor reading is outside the permitted threshold for adjusting the center i.e. this is user movement
      if(abs(centered[i] -oldCentered[i])>variationThreshold) {
        withinBounds = false;
        if (debug==7) {Serial.print("Sensor ");Serial.print(i);Serial.print(" Centered = ");Serial.print(centered[i]);Serial.print(" oldCentered = ");Serial.print(oldCentered[i]);Serial.print(" Variation = ");Serial.println(abs(centered[i] -oldCentered[i]));}
      }
    }
    if (withinBounds) {
      // possible new center position. check if the values have been stable for sufficient time
      //Serial.println("withinBounds");
      if ((millis() - startTime)>stableTime)
        {
          readAllFromSensors(centerPoints);
          if (debug == 7) Serial.println("reset centerPoints");
          greaterThanThreshold = false;
          firstTime = true;
        }
    } else {
      //no change or user movement
      if (debug == 7) Serial.println("no change");
      greaterThanThreshold = false;
      firstTime = true;
    }
   }

// check if we have moved from the last center position (user movement or center drift)
   for(int i=0;i<8;i++){
    if((!greaterThanThreshold) && (abs(centered[i])>variationThreshold))  greaterThanThreshold = true; // if any user movement is detected then it is not drift
    }

// if there is movement detected and this is the first time it has been detected then remember this position and start timer.
  if ((greaterThanThreshold) && (firstTime)) {
    for(int i=0;i<8;i++){
      oldCentered[i]=centered[i];  // if oldCentered Changes we need to readjust it
    }
    firstTime = false;
    startTime = millis();
  }
#endif // include_AutoRecenter
  // end of C013

  // Filter movement values. Set to zero if movement is below deadzone threshold.
  // *JC - Changed operation so there isn't a sudden jump when the value first falls outside deadzone
  for(int i=0; i<8; i++){
    if(centered[i]<DEADZONE && centered[i]>-DEADZONE) {
      centered[i] = 0;
    } else {
      int sgn = centered[i] / abs(centered[i]);
      centered[i] = sgn*(abs(centered[i])-DEADZONE);
    }
  }
  // Report centered Sensor values. Filtered for deadzone. Approx -500 to +500, locked to zero at idle
  if(debug == 3){
    Serial.print("HES0:"); Serial.print(centered[0]); Serial.print(",");
    Serial.print("HES1:"); Serial.print(centered[1]); Serial.print(",");
    Serial.print("HES2:"); Serial.print(centered[2]); Serial.print(",");
    Serial.print("HES3:"); Serial.print(centered[3]); Serial.print(",");
    Serial.print("HES6:"); Serial.print(centered[4]); Serial.print(",");
    Serial.print("HES7:"); Serial.print(centered[5]); Serial.print(",");
    Serial.print("HES8:"); Serial.print(centered[6]); Serial.print(",");
    Serial.print("HES9:"); Serial.print(centered[7]); Serial.print(",");
    Serial.print("But0:"); Serial.print(buttonReads[0]); Serial.print(",");
    Serial.print("But1:"); Serial.print(buttonReads[1]); Serial.print(",");
    Serial.print("But2:"); Serial.print(buttonReads[2]); Serial.print(",");
    Serial.print("But3:"); Serial.println(buttonReads[3]);  
  }

  // Doing all through arithmetic contribution by fdmakara
  // Integer has been changed to 16 bit int16_t to match what the HID protocol expects.
  int16_t transX, transY, transZ, rotX, rotY, rotZ; // Declare movement variables at 16 bit integers
  
  // *JC - Replaced Joystick calculations with ones for the Hall Effect Sensors
  // C011 replaced the divide by 2 on shorter equasions and divide by 4 on longer ones with a configurable weight calculation
  // C012 All movement calvulations now include all sensors even if their impact on the values returned will be small
  #ifdef include_UseAllSensorsForAllMovement
    transX = (centered[HES1]-centered[HES0]+centered[HES6]-centered[HES7]+centered[HES2]+centered[HES3]+centered[HES9]+centered[HES8])*transXWeight/weightDivisor;  //C012
    transY = (centered[HES2]-centered[HES3]+centered[HES9]-centered[HES8]+centered[HES1]+centered[HES0]+centered[HES6]+centered[HES7])*transYWeight/weightDivisor;  //C012
  #else
    transX = (centered[HES1]-centered[HES0]+centered[HES6]-centered[HES7])*transXWeight/weightDivisor;  // pre C012
    transY = (centered[HES2]-centered[HES3]+centered[HES9]-centered[HES8])*transYWeight/weightDivisor;  //pre C012
  #endif 
  transZ = (centered[HES0]+centered[HES1]+centered[HES2]+centered[HES3]+centered[HES6]+centered[HES7]+centered[HES8]+centered[HES9])*transZWeight/weightDivisor;
  #ifdef include_UseAllSensorsForAllMovement
    rotX = (centered[HES0]+centered[HES1]-centered[HES6]-centered[HES7]+centered[HES2]-centered[HES3]+centered[HES9]-centered[HES8])*rotXWeight/weightDivisor;  // C012
    rotY = (centered[HES8]+centered[HES9]-centered[HES2]-centered[HES3]-centered[HES1]+centered[HES0]-centered[HES6]+centered[HES7])*rotYWeight/weightDivisor;  // C012
  #else
    rotX = (centered[HES0]+centered[HES1]-centered[HES6]-centered[HES7])*rotXWeight/weightDivisor;  // pre C012
    rotY = (centered[HES8]+centered[HES9]-centered[HES2]-centered[HES3])*rotYWeight/weightDivisor;  // pre C012
  #endif
  rotZ = (centered[HES0]+centered[HES2]+centered[HES6]+centered[HES8]-centered[HES1]-centered[HES3]-centered[HES7]-centered[HES9])*rotZWeight/weightDivisor; // C001 *JC - changed default direction of rotation

  #ifdef include_IgnoreSmallChanges 
  // This section by Jonas Edvinsson
  // C010... (After existing code where transX, transY, transZ, rotX, rotY, rotZ are calculated) ...
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

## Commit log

2024-07-11 Add files via upload
    Wiring diagram and Arduino sketch
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2024-07-11 Update README.md added new photo to show magnet movement
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2024-07-11 Fusion 360 design file added
    3D printed parts design file
    [Hall Effect Spacemouse.f3d]
2024-07-11 Added STL files to repository
    [Arduino Plate.stl, Base.stl, Bolt plate.stl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]
2024-07-12 Added STEP file of design
    [Hall Effect Spacemouse.step]
2024-07-13 Update README.md Added table of button report functions
2024-07-16 Update HE_Spacemouse.ino only send button report if button pressed and reversed linear Z movement
    [HE_Spacemouse.ino]
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2024-07-24 Added M4 bolt and nuts to Parts list. Thanks to onolox for pointing out I left it out. Also added 3d render of layers.
2024-07-25 3 changes made. New state machine for switch function, reversed direction of RotZ, Added code to allow 3DC default movements to be selected.
    C001 - Reversed the default direction of RotZ
    C002 - Added state machine to supress the default actions for two buttons when pressed together to cause a third action to occur. i.e. press the left and right button together to get the 3DC configuration menu to appear.
    C003 - Added a global variable to switch between default 3DC movements as shown in the tutorials and the default movements provided by the Teaching Tech code.
    [HE_Spacemouse.ino]
2024-07-26 Corrected the required lengths of piano wire.
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2024-07-29 Added eBay as a possible source and adjusting tension by moving wire holder.
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2024-08-01 Added 1mm TPU spring replacement
2024-08-01 STL files for possible TPU replacement for springs.
    [TPU Hook.stl, TPU Spring.stl]
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2024-08-05 Rename TPU Spring.stl to TPU Spring 0.1mm.stl
    [TPU Spring 0.1mm.stl]
2024-08-05 Added two thinner TPU spring models
    Added 0.8mm and 0.6mm TPU "springs" for lighter tension.
    [TPU Spring 0.6mm.stl, TPU Spring 0.8mm.stl]
2024-08-05 Added missing M3 bolts and nuts as pointed out bu @Aurion62_2004072
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2024-08-06 bug fix for key report. Now sending a zero report when keys released.
    [HE_Spacemouse.ino]
2024-08-07 Update and rename TPU Spring 0.1mm.stl to TPU Spring 0.1x15mm.stl
    [TPU Spring 0.1x15mm.stl]
2024-08-07 Update and rename TPU Spring 0.6mm.stl to TPU Spring 0.6x15mm.stl
    [TPU Spring 0.6x15mm.stl]
2024-08-07 Rename TPU Spring 0.8mm.stl to TPU Spring 0.8x15mm.stl
    [TPU Spring 0.8x15mm.stl]
2024-08-08 fixed a bug introduced in the last release of code.
    In the last release, I changed the operation of the key code and key report code to send a zero report at the end so that the 3DConnexion software knows when a button on the mouse has been released. While this worked I accidently introduced a bug where multiple keys could be sent in the same report when only the logical key was wanted. A simple one line fix was needed. This was in prior releases of the code but removed from the last one due to the change in operation. Now it is back
    [HE_Spacemouse.ino]
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2024-11-16 Added STL files for crisscross TPU spring design
    Added TPU "springs" with thinner mounting points so that two springs can be held on each TPU hook. Also added a lower height bolt plate to give more flexibility on options.
    [Bolt plate for TPU springs.stl, Thin TPU Spring 0.6x16mm.stl, Thin TPU Spring 0.6x17mm.stl]
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2024-11-24 small hook version of TPU spring
    [TPU Hook V2.stl, TPU Spring 0.6x17mm V2.stl, TPU Spring 0.6x18mm v2.stl]
2024-11-24 Update on correct distance between magnet plat and sensors
2024-11-25 Cap keeper in TPU to hold knob cap to top of knob if loose
    [TPU cap keeper.stl]
2024-12-01 Created directory to hold STL file of the template for creating silicone feet
2024-12-01 Silicon template uploaded
    [silicone template.stl]
2025-01-08 Made it more obvious how to recognise the north pole of the magnet.
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2025-02-06 changed STL files for smaller case version
    New case, knob and button needed for smaller case version. Plus knob cap with more space internally.
    [Button v3 (extended -smaller case).stl, Case (smaller).stl, Spacemouse knob cap hollow.stl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]
2025-03-17 Added Base for smaller case
    Added a Base for the smaller case design as the original design base didn't fit well as pointed out by Birdy67 on Printables.
    [Base for smaller case.stl]
2025-03-17 Update to add Base re Birdy67 comment
    Added update to reflect the addition of a base STL to the repository as the original base didn't fit well with the smaller case.
2025-04-08 Added modified design files as requested by vrplanet on Printables
    [Hall Effect Spacemouse smaller V3.step]
2025-05-03 Added a note to answer a query on AndunHH Spacemouse CR #78
    A query on AndunHH's Spacemouse CR #78 asked why debug level 1 used 5V. Jarno Boks has modified AndunHH's code to run on this mouse and its variations but kept the debug level 1 from my code. I have 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
2025-08-09 Added comment about TPU spring from Trev-erse
    A new design of TPU spring appeared in my suggested YouTube shorts. It looks interesting. It would require a bit of a redesign to use now but If I were to start again, it would be something I would investigate.
2025-08-09 More pseudo buttons
    Added two new pseudo buttons operated by pressing the front button and one of the other two buttons at the same time.
    Pressing the front button together with the left button starts and stops rotation lock.
    Pressing the front button together with the right button is fit to screen.
    All buttons can be reassigned through the 3dConnections configuration menu which you can get at by pressing both the button on the left and the button on the right simultaneously.
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2025-08-14 Files associated with wave spring attempt.
    [Spacemouse knob Wave spring (smaller case).stl, lower mount.stl, upper mount side 1.stl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]
2025-08-14 modified button mapping giving cyclic button
    Modified button mapping and made the front button cycle through three different views.
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2025-08-18 Parts and design uploaded for triple wave spring
    I had to run the triple wave spring STL file through an STL simplifier to get it to upload.
    [Hall Effect Spacemouse smaller V3.step, lower mount.stl]
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2025-08-26 uploaded files for new version of wave spring
    [Wave Spring for 95A TPU v3.stl, magnet plate wave spring holder.stl]
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2025-11-30 Update README with OnShape version and variable tips
    Added update about OnShape version of the wave spring and provided guidance on variable adjustments for different TPU types.
2026-05-20 Added 3 movement related changes
    Added three movemnt related changes.
    C010 - ignore small 'noise' movements if there is a larger movement.
    C011 - Add weight to each movement axis to increase or reduce that movements affect.
    C013 - Included all 8 sensors in every movements calculation.
    [HE_Spacemouse.ino]
2026-07-21 Add README for dual material spring design
    Added instructions for printing the dual material spring.
2026-07-21 New variation of Innerbushmans spring/magnet plate
    A dual material version of Innerbushmans TPU spring/magnet plate design.
    [Alternate TPU spring for spring holder.stl, Alternate TPU spring holder with cutouts.stl, Alternate TPU spring.FCStd]
2026-07-21 Add update on dual material spring design
    Added update about dual material version of the spring and magnet plate design, including details on printing process and comparisons with previous versions.
2026-07-22 Deadzone discussion and Auto recentre
    My thoughts on deadzone values and a couple of code changes.
    Auto recentering and sensitivity selection.
2026-07-22 Added Auto recenter and sensitivity selection
    Added two changes one that allows the mouse to detect if it needs to update its centered readings. The other allows the sensitivity of the mouse to be changes by pressing the centre and right buttons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

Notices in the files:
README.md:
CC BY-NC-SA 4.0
